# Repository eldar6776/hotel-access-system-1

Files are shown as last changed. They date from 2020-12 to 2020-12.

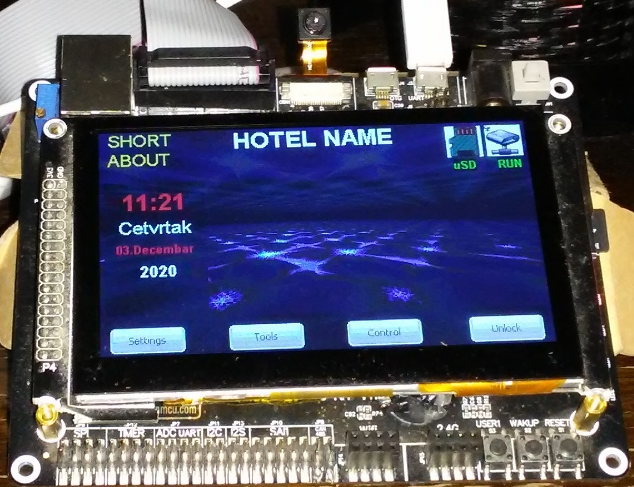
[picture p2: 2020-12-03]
RedDragon429.bmp

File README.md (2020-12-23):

# hotel_access_control_1
The system consists of hotel controllers (RedDragon429 development platform), room controller (STM32F103C8T6 designed pcb), room thermostat (STM32F746ZET designed pcb) and writer/reader for MIFARE cards. RS485 is used to communicate between hotel controller and (0xfffd) room controllers. Each room controller has an individual 16-bit address, a 16-bit group address and a 16-bit broadcast address. All addresses can be adjusted. Each room controller generates and memorates the event log that is transferred every 3 to 10 seconds to the hotel controller, which is still downloaded by the PC application. Communication inside the room is single-wired data + GND. The hotel controller has embedded web server for setting up, update room controllers, temostates, display image change, and more... Tftp server is used transfer new files to a hotel controller uSD card over the network. The complete hardware design is in the "hw" folder.

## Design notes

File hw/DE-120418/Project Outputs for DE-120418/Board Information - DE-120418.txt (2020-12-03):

Board Information Report
Filename     : F:\SkyDrive\OtvoreniProjekti\HotelSaplast\hw\DE-120418\DE-120418.PcbDoc
Date         : 13.4.2018.
Time         : 14:25:55
Time Elapsed : 00:00:00

General
    Board Size, 690milsx830mils
    Components on board, 23
count : 2

Routing Information
    Routing completion, 98,15%
    Connections, 54
    Connections routed, 53
    Connections remaining, 1
count : 4

Layer, Arcs, Pads, Vias, Tracks, Texts, Fills, Regions, ComponentBodies
    Top Layer, 0, 51, 0, 98, 0, 0, 1, 0
    Bottom Layer, 0, 20, 0, 87, 0, 1, 3, 0
    Mechanical 1, 0, 0, 0, 0, 0, 0, 0, 6
    Mechanical 13, 1, 0, 0, 8, 0, 0, 0, 2
    Mechanical 15, 0, 0, 0, 12, 0, 0, 0, 0
    Multi-Layer, 0, 14, 27, 0, 0, 0, 1, 0
    Top Paste, 0, 0, 0, 0, 0, 0, 0, 0
    Top Overlay, 3, 0, 0, 41, 30, 0, 0, 0
    Top Solder, 0, 0, 0, 0, 0, 0, 0, 0
    Bottom Solder, 0, 0, 0, 0, 0, 0, 0, 0
    Bottom Overlay, 0, 0, 0, 9, 20, 0, 0, 0
    Bottom Paste, 0, 0, 0, 0, 0, 0, 0, 0
    Drill Guide, 0, 0, 0, 0, 0, 0, 0, 0
    Keep-Out Layer, 0, 0, 0, 0, 0, 0, 0, 0
    Drill Drawing, 0, 0, 0, 0, 0, 0, 0, 0
count : 15

Drill Pairs, Vias
    Top Layer - Bottom Layer, 27
count : 1

Non-Plated Hole Size, Pads, Vias
count : 0

Plated Hole Size, Pads, Vias
    0mils, 71, 0
    12.992mils, 0, 16
    15.748mils, 0, 11
    35.433mils, 14, 0
count : 4

Non-Plated Slot Size / Length, Pads
count : 0

Plated Slot Size / Length, Pads
count : 0

Non-Plated Square Hole Size, Pads
count : 0

Plated Square Hole Size, Pads
count : 0

Top Layer Annular Ring Size, Count
    12.992mils, 16
    15.748mils, 11
    23.622mils, 14
count : 3

Mid Layer Annular Ring Size, Count
    12.992mils, 16
    15.748mils, 11
    23.622mils, 14
count : 3

Bottom Layer Annular Ring Size, Count
    12.992mils, 16
    15.748mils, 11
    23.622mils, 14
count : 3

Pad Solder Mask, Count
    4mils, 85
count : 1

Pad Paste Mask, Count
    0mils, 85
count : 1

Pad Pwr/Gnd Expansion, Count
    20mils, 85
count : 1

Pad Relief Conductor Width, Count
    10mils, 85
count : 1

Pad Relief Air Gap, Count
    10mils, 85
count : 1

Pad Relief Entries, Count
    4, 85
count : 1

Via Solder Mask, Count
    4mils, 27
count : 1

Via Pwr/Gnd Expansion, Count
    20mils, 27
count : 1

Track Width, Count
    3.937mils, 20
    7.874mils, 46
    10mils, 106
    20mils, 43
    30mils, 40
count : 5

Arc Line Width, Count
    3.937mils, 1
    9.843mils, 3
count : 2

Arc Radius, Count
    4.921mils, 3
    19.685mils, 1
count : 2

Arc Degrees, Count
    360, 4
count : 1

Text Height, Count
    20mils, 48
    60mils, 2
count : 2

Text Width, Count
    3mils, 48
    10mils, 2
count : 2

Net Track Width, Count
    10mils, 19
count : 1

Net Via Size, Count
    31.496mils, 19
count : 1

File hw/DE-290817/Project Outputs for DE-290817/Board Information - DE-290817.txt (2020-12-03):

Board Information Report
Filename     : C:\Users\eldar\Desktop\HotelRoomAccessControlUnit\hw\DE-290817.PcbDoc
Date         : 20.09.2017.
Time         : 18:17:32
Time Elapsed : 00:00:00

General
    Board Size, 2755.906milsx5118.11mils
    Components on board, 176
count : 2

Routing Information
    Routing completion, 100,00%
    Connections, 430
    Connections routed, 430
    Connections remaining, 0
count : 4

Layer, Arcs, Pads, Vias, Tracks, Texts, Fills, Regions, ComponentBodies
    Top Layer, 5, 460, 0, 1414, 0, 10, 12, 0
    Bottom Layer, 7, 26, 0, 742, 0, 5, 26, 0
    Mechanical 1, 0, 0, 0, 24, 2, 0, 0, 21
    Mechanical 13, 7, 0, 0, 100, 0, 1, 0, 20
    Mechanical 15, 0, 0, 0, 150, 0, 0, 0, 0
    Multi-Layer, 0, 68, 271, 0, 0, 0, 1, 0
    Top Paste, 0, 0, 0, 0, 0, 0, 0, 0
    Top Overlay, 41, 0, 0, 413, 358, 0, 0, 0
    Top Solder, 0, 0, 0, 0, 0, 0, 0, 0
    Bottom Solder, 0, 0, 0, 0, 0, 0, 0, 0
    Bottom Overlay, 0, 0, 0, 69, 10, 0, 0, 0
    Bottom Paste, 0, 0, 0, 0, 0, 0, 0, 0
    Drill Guide, 0, 0, 0, 0, 0, 0, 0, 0
    Keep-Out Layer, 3, 0, 0, 4, 0, 0, 0, 0
    Drill Drawing, 0, 0, 0, 0, 0, 0, 0, 0
count : 15

Drill Pairs, Vias
    Top Layer - Bottom Layer, 271
count : 1

Non-Plated Hole Size, Pads, Vias
count : 0

Plated Hole Size, Pads, Vias
    0mils, 486, 0
    15.748mils, 0, 271
    23.622mils, 2, 0
    30mils, 6, 0
    31.496mils, 2, 0
    35.433mils, 46, 0
    47.244mils, 12, 0
count : 7

Non-Plated Slot Size / Length, Pads
count : 0

Plated Slot Size / Length, Pads
count : 0

Non-Plated Square Hole Size, Pads
count : 0

Plated Square Hole Size, Pads
count : 0

Top Layer Annular Ring Size, Count
    11.811mils, 12
    15.748mils, 271
    21.654mils, 2
    23.622mils, 48
    30mils, 6
count : 5

Mid Layer Annular Ring Size, Count
    11.811mils, 12
    15.748mils, 271
    21.654mils, 2
    23.622mils, 48
    30mils, 6
count : 5

Bottom Layer Annular Ring Size, Count
    11.811mils, 12
    15.748mils, 271
    21.654mils, 2
    23.622mils, 48
    30mils, 6
count : 5

Pad Solder Mask, Count
    4mils, 551
    31.496mils, 3
count : 2

Pad Paste Mask, Count
    0mils, 554
count : 1

Pad Pwr/Gnd Expansion, Count
    20mils, 554
count : 1

Pad Relief Conductor Width, Count
    10mils, 554
count : 1

Pad Relief Air Gap, Count
    10mils, 554
count : 1

Pad Relief Entries, Count
    4, 554
count : 1

Via Solder Mask, Count
    4mils, 271
count : 1

Via Pwr/Gnd Expansion, Count
    20mils, 271
count : 1

Track Width, Count
    1.969mils, 24
    3.937mils, 234
    5mils, 301
    7.874mils, 357
    10mils, 1234
    15mils, 3
    19.685mils, 60
    20mils, 317
    30mils, 306
    39.37mils, 7
    50mils, 33
    60mils, 40
count : 12

Arc Line Width, Count
    3.937mils, 7
    5mils, 8
    7.874mils, 3
    9.843mils, 24
    10mils, 14
    23.622mils, 3
    39.37mils, 4
count : 7

Arc Radius, Count
    4.921mils, 24
    11.811mils, 3
    12.5mils, 1
    12.598mils, 8
    19.685mils, 7
    28.248mils, 5
    30.248mils, 3
    41.339mils, 2
    53.151mils, 1
    54.083mils, 1
    60.208mils, 3
    196.85mils, 2
    236.221mils, 1
    314.961mils, 2
count : 14

Arc Degrees, Count
    48, 1
    57, 2
    77, 1
    140, 3
    180, 1
    280, 1
    360, 54
count : 7

Text Height, Count
    15mils, 5
    19.685mils, 346
    20mils, 4
    30mils, 4
    60mils, 10
    118.11mils, 1
count : 6

Text Width, Count
    3.937mils, 351
    4mils, 4
    5mils, 4
    6mils, 2
    10mils, 8
    19.685mils, 1
count : 6

Net Track Width, Count
    5mils, 108
count : 1

Net Via Size, Count
    50mils, 108
count : 1

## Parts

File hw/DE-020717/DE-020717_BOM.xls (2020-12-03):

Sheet: BOM Report
Bill of Materials |  |  | Bill of Materials For PCB Document [DE-020717.PcbDoc]
Source Data From: |  | DE-020717.PcbDoc
Project: |  | DE-020717.PrjPcb
Variant: |  | None
Creation Date: | 2.6.2018. | 16:11:59
Print Date: | 43253 | 43253.67921
Footprint | Comment | LibRef | Designator | Description | Quantity
0603 | 100nF | C0603 | C1, C2, C3, C4, C5, C6, C7, C8, C12, C13, C14, C15, C16, C17, C19, C20, C21, C22, C23, C24, C25, C26, C27, C28, C30, C31, C32, C33, C34, C36, C37, C38, C39, C40, C41, C42, C44, C45, C46, C48, C49, C50, C51, C53, C55, C56, C66, C68, C71, C72, C74, C75, C79 | Ceramic Chip Capacitor - Standard | 59
0805 | C0805 | C0805 | C9, C10, C35 | Ceramic Chip Capacitor - Standard | 3
0603 | C0603 | C0603 | C11, C18, C29, C43, C47, C52 | Ceramic Chip Capacitor - Standard | 6
0805 | 4u7 | C0805 | C54, C57, C70, C73, C81 | Ceramic Chip Capacitor - Standard | 5
0603 | 1uF | C0603 | C67 | Ceramic Chip Capacitor - Standard | 1
3528 | 22uF/16V | 293D156X0004B2 | C83, C84 | Tantamount Commercial, Surface Mount Solid Tantalum Chip Capacitor: 15uF, 20% Tolerance, 4 WVDC @ +85°C, Surge = 5.2V | 2
3528 | 47uF/10V | 293D156X0004B2 | C85, C86 | Tantamount Commercial, Surface Mount Solid Tantalum Chip Capacitor: 15uF, 20% Tolerance, 4 WVDC @ +85°C, Surge = 5.2V | 2
3528 | 100uF | 293D156X0004B2 | C87 | Tantamount Commercial, Surface Mount Solid Tantalum Chip Capacitor: 15uF, 20% Tolerance, 4 WVDC @ +85°C, Surge = 5.2V | 1
0805 | 10uF | C0805 | C90, C93, C94 | Ceramic Chip Capacitor - Standard | 3
1.6X0.8X0.8A | HSMH-C190 | HSMH-C190 | D1 | Surface Mount Chip LED, Red | 1
ONSC-SOD-123-2-425-04_V | STPS1L40M | SMMSD301T1G | D2 | Schottky Barrier Diode, 2-Pin SOD-123, Pb-Free, Tape and Reel | 1
0603 | BLM15AG121 | Inductor_SMD | L1, L2, L3, L5, L7, L8, L9, L10 | Inductor | 8
WE-LQS 252012 | 4,7uH SMD Inductor | SMD inductor | L4 | WE-LQS SMD Power Inductor, L=4.7 µH | 1
HDR1X2 | 3VBAT | NOT FEEDED | P1 | Header, 2-Pin | 1
HDR1X2 | AMBIENT_LIGHT | NOT FEEDED | P2 | Header, 2-Pin | 1
HDR1X2 | AMBIENT_TEMPERATURE | NOT FEEDED | P3 | Header, 2-Pin | 1
10 pin PFC | TOUCH_SCREEN | TS_Connector | P4 | 10 pin PFC connector bottom contacts | 1
HDR2X4 | nRF24L01 | NOT FEEDED | P7 | Header, 4-Pin, Dual row | 1
40 pin FPC | 480x272 RGB TFT LCD AML043056B0-40 | TFT LCD Connector | P8 | 40 pin pfc connector bottom contacts | 1
HDR1X3 | ST-Link Debbuger | NOT FEEDED | P9 | Header, 3-Pin | 1
HDR2X5 | EXPAND | NOT FEEDED | P10 | Header, 5-Pin, Dual row | 1
HDR1X8 | FANCOIL_INTERFACE | NOT FEEDED | P11 | Header, 8-Pin | 1
HDR1X8 | POWER_&_COM | NOT FEEDED | P12 | Header, 8-Pin | 1
SOT23_N | 2N7002 | 2N7002 | Q1, Q2, Q3, Q4 | N-channel Enhancement Mode Vertical D-MOSFET | 4
2-0402 | 10K | ERJ2GE | R1, R2, R3, R4, R5, R6, R7, R8, R9, R10, R11, R14, R15, R16, R17, R18, R19, R20 | Thick Film Chip Resistor, 1 Ohm to 2.2M Ohm Range, 5% Tolerance, 0402 Size, 0.063 W | 18
ERA-0603 | 10K | ERA3Y | R12, R13, R22, R28, R39, R60, R61 | Rectangular Thick Film Chip Resistor, 10 Ohm to 330k Ohm Range, 0.1% and 0.5% Tolerance, 0603 Size, 0.063 W | 7
ERA-0603 | 2K7 | ERA3Y | R21, R23, R25, R26 | Rectangular Thick Film Chip Resistor, 10 Ohm to 330k Ohm Range, 0.1% and 0.5% Tolerance, 0603 Size, 0.063 W | 4
ERA-0603 | 0R | ERA3Y, ERA3Y, ERA3Y, ERA3Y, ERA3Y, ERAV | R24, R27, R34, R36, R37, R48 | Rectangular Thick Film Chip Resistor, 10 Ohm to 330k Ohm Range, 0.1% and 0.5% Tolerance, 0603 Size, 0.063 W, Rectangular Thick Film Chip Resistor, 10 Ohm to 330k Ohm Range, 0.1% and 0.5% Tolerance, 0603 Size, 0.063 W, Rectangular Thick Film Chip Resistor, | 6
ERA-0603 | 560R | ERA3Y | R29, R41 | Rectangular Thick Film Chip Resistor, 10 Ohm to 330k Ohm Range, 0.1% and 0.5% Tolerance, 0603 Size, 0.063 W | 2
ERA-0603 | 1K | ERA3Y | R30, R42, R43 | Rectangular Thick Film Chip Resistor, 10 Ohm to 330k Ohm Range, 0.1% and 0.5% Tolerance, 0603 Size, 0.063 W | 3
ERA-0603 | 330R | ERA3Y | R31 | Rectangular Thick Film Chip Resistor, 10 Ohm to 330k Ohm Range, 0.1% and 0.5% Tolerance, 0603 Size, 0.063 W | 1
ERA-0603 | NF | ERA3Y | R32, R33, R38 | Rectangular Thick Film Chip Resistor, 10 Ohm to 330k Ohm Range, 0.1% and 0.5% Tolerance, 0603 Size, 0.063 W | 3
ERA-0603 | 220R | ERA3Y | R35, R44 | Rectangular Thick Film Chip Resistor, 10 Ohm to 330k Ohm Range, 0.1% and 0.5% Tolerance, 0603 Size, 0.063 W | 2
ERA-0603 | 2K2 | ERA3Y, ERAV, ERAV, ERAV, ERAV, ERAV, ERA3Y | R40, R51, R52, R53, R54, R55, R59 | Rectangular Thick Film Chip Resistor, 10 Ohm to 330k Ohm Range, 0.1% and 0.5% Tolerance, 0603 Size, 0.063 W, Metal Film Thermosensitive Chip Resistor, 0.56 Ohm to 10k Ohm Range, 5% Tolerance, 0603 Size, 0.063 W, Metal Film Thermosensitive Chip Resistor, 0 | 7
ERA-0603 | 100K | ERAV | R45 | Metal Film Thermosensitive Chip Resistor, 0.56 Ohm to 10k Ohm Range, 5% Tolerance, 0603 Size, 0.063 W | 1
ERA-0603 | 4K7 | ERAV, ERA3Y | R46, R58 | Metal Film Thermosensitive Chip Resistor, 0.56 Ohm to 10k Ohm Range, 5% Tolerance, 0603 Size, 0.063 W, Rectangular Thick Film Chip Resistor, 10 Ohm to 330k Ohm Range, 0.1% and 0.5% Tolerance, 0603 Size, 0.063 W | 2
ERA-0805 | 10R | ERAS | R47 | Metal Film Thermosensitive Chip Resistor, 0.56 Ohm to 10k Ohm Range, 5% Tolerance, 0805 Size, 0.1 W | 1
ERA-0603 | 1K2 | ERA3Y | R57 | Rectangular Thick Film Chip Resistor, 10 Ohm to 330k Ohm Range, 0.1% and 0.5% Tolerance, 0603 Size, 0.063 W | 1
LQFP-144_20X20mm | STM32F746ZET | STM32F74XZXT | U1 | STM32F746ZET ARM Cortex M7 microcontroller | 1
MICT-P-86_N | MT48LC4M32B2P-6A | MT48LC4M32B2P-6A | U2 | 128Mb PC133 SDR SDRAM, 4Mb x 32, 6ns, 3.3V, 0 to 70 degC, 86-Pin TSOP, Pb-Free | 1
419A-01_N | MC74VHC1GT14DFT1 | MC74VHC1GT14DFT1 | U3, U5 | Schmitt-Trigger Inverter / Logic Level Shifter with LSTTL-Compatible Inputs | 2
SO16_N | ULN2003A | ULN2003D | U4 | Seven Darlington Array | 1
QFN8_V | STLD40DPUR | STLD40DPUR | U6 | White Led Power Supply For Large Display Backlight, 8-Pin VFDFPN, Tape and Reel | 1
NSO8_N | MAX485CSA | MAX485CSA | U8 | Low-Power, Slew-Rate-Limited RS-485/RS-422 Transceiver | 1
SOP8_N | M24128RMN1 | M24128RMN1 | U9 | 128 K Serial I˛C Bus EEPROM | 1
MICT-SE-8_N | N25Q128A13ESE40E | N25Q128A13ESE40E | U10 | 128 Mb (x1/x2/x4) Serial NOR Flash Memory with Multi I/O, 108 MHz, 2.7 to 3.6 V, 8-pin SO8 Wide (SE), Tray | 1
TO220 | DC/DC BUCK | NOT FEEDED | U11 | Positive Voltage Regulator, 5V, 3-Pin TO-220 | 1
ZZ311 | REG1117-3.3 | REG1117-3.3 | U12 | 800mA and 1A Low Dropout Positive Regulator 2.85V, 3.3V, 5V, and Adjustable | 1
CSM-7 | ECS-110-S-5P | 8MHz | Y1 | Crystal Oscillator | 1
R38 | RTC | 32,768kHz | Y2 | Crystal Oscillator | 1
 |  |  |  |  | 178
Approved |  | Notes

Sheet: Project Information
Project Full Path | F:\SkyDrive\OtvoreniProjekti\HotelSaplast\hw\DE-020717\DE-020717.PrjPcb
Project Filename | DE-020717.PrjPcb
Variant Name | None
Data-Source Filename | DE-020717.PcbDoc
Data-Source Full Path | F:\SkyDrive\OtvoreniProjekti\HotelSaplast\hw\DE-020717\DE-020717.PcbDoc
Title | Bill of Materials For PCB Document [DE-020717.PcbDoc]
Total Quantity | 178
Report Time | 16:11:59
Report Date | 2.6.2018.
Report Date & Tine | 2.6.2018. 16:11:59
Output Name | Bill of Materials
Output Type | BOM_PartType
Output Generator Name | BOM
Output Generator Description | Bill of Materials

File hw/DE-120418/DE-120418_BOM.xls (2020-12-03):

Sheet: BOM Report
Bill of Materials |  |  | AUDIO CODEC
Source Data From: |  | DE-120418.PrjPcb
Project: |  | DE-120418.PrjPcb
Variant: |  | None
Creation Date: | 13.4.2018. | 14:25:38
Print Date: | 43203 | 43203.60118
Footprint | Comment | LibRef | Designator | Description | Quantity
3528 | 47uF/10V | 293D156X0004B2 | C1 | Tantamount Commercial, Surface Mount Solid Tantalum Chip Capacitor: 15uF, 20% Tolerance, 4 WVDC @ +85°C, Surge = 5.2V | 1
0805 | 10uF | C0805 | C2, C9 | Ceramic Chip Capacitor - Standard | 2
0603 | 100nF | C0603 | C3, C11, C12 | Ceramic Chip Capacitor - Standard | 3
0805 | 4u7 | C0805 | C4, C6, C7, C13, C14 | Ceramic Chip Capacitor - Standard | 5
3528 | 100uF | 293D156X0004B2 | C8 | Tantamount Commercial, Surface Mount Solid Tantalum Chip Capacitor: 15uF, 20% Tolerance, 4 WVDC @ +85°C, Surge = 5.2V | 1
0603 | 220pF | C0603 | C15 | Ceramic Chip Capacitor - Standard | 1
0603 | 1uF | C0603 | C16, C17 | Ceramic Chip Capacitor - Standard | 2
INDC1608L | BLM15AG121 | Inductor_SMD | L1 | Inductor | 1
HDR1X2 | SPEAKER | Header 2 | P1 | Header, 2-Pin | 1
HDR1X2 | MIC | Header 2 | P2 | Header, 2-Pin | 1
HDR2X5 | AUDIO_CODEC | Header 5X2 | P3 | Header, 5-Pin, Dual row | 1
ERA-0603 | 47K | ERAV | R1 | Metal Film Thermosensitive Chip Resistor, 0.56 Ohm to 10k Ohm Range, 5% Tolerance, 0603 Size, 0.063 W | 1
ERA-0603 | 680R | ERAV | R2 | Metal Film Thermosensitive Chip Resistor, 0.56 Ohm to 10k Ohm Range, 5% Tolerance, 0603 Size, 0.063 W | 1
ERA-0603 | 0R | ERAV | R3 | Metal Film Thermosensitive Chip Resistor, 0.56 Ohm to 10k Ohm Range, 5% Tolerance, 0603 Size, 0.063 W | 1
QFN32_N | WM8976 | WM8976 | U1 | Stereo CODEC with speaker driver | 1
 |  |  |  |  | 23
Approved |  | Notes

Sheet: Project Information
Project Full Path | F:\SkyDrive\OtvoreniProjekti\HotelSaplast\hw\DE-120418\DE-120418.PrjPcb
Project Filename | DE-120418.PrjPcb
Variant Name | None
Data-Source Filename | DE-120418.PrjPcb
Data-Source Full Path | F:\SkyDrive\OtvoreniProjekti\HotelSaplast\hw\DE-120418\DE-120418.PrjPcb
Title | AUDIO CODEC
Total Quantity | 23
Report Time | 14:25:38
Report Date | 13.4.2018.
Report Date & Tine | 13.4.2018. 14:25:38
Output Name | Bill of Materials
Output Type | BOM_PartType
Output Generator Name | BOM
Output Generator Description | Bill of Materials

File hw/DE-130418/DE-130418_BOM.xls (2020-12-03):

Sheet: BOM Report
Bill of Materials |  |  | Bill of Materials For PCB Document [DE-130418.PcbDoc]
Source Data From: |  | DE-130418.PcbDoc
Project: |  | DE-130418.PrjPcb
Variant: |  | None
Creation Date: | 13.4.2018. | 16:10:28
Print Date: | 43203 | 43203.67416
Footprint | Comment | LibRef | Designator | Description | Quantity
0603 | 100nF | C0603 | C1 | Ceramic Chip Capacitor - Standard | 1
0805 | 4u7 | C0805 | C2 | Ceramic Chip Capacitor - Standard | 1
ONSC-TO-220-3-221A-07 | BTA16-600 | BTA08-600BW3G | D1, D2, D3 | Triacs, Silicon Bidirectional Thyristor, 3-Pin TO-220, Pb-Free, Tube | 3
15-43-8501 | 15-43-8501 | 15-43-8501 | J1 | Right Angle, Standard Profile, RJ-45 Keyed, Unshielded PCB Jack | 1
TERMINAL BLOK 2 | 220VAC | TERMINAL BLOK 2 | P1 | Terminal blok konektor 5 mm | 1
TERMINAL BLOK 2 |  | TERMINAL BLOK 2 | P2, P3 | Terminal blok konektor 5 mm | 2
HDR1X3 | AUX | Header 3 | P4 | Header, 3-Pin | 1
ERA-0805 | 330R | ERAS | R1, R4, R7 | Metal Film Thermosensitive Chip Resistor, 0.56 Ohm to 10k Ohm Range, 5% Tolerance, 0805 Size, 0.1 W | 3
RD6.35x2.3 | 360R | ERDS1T | R2, R3, R5, R6, R8, R9 | Carbon Film Resistor, 1 Ohm to 3.3M Ohm Range, 5% Tolerance, 0.5 W | 6
DIP6 | MOC3081 | MOC3081 | U1, U2, U3 | Zero-Cross Optoisolator Triac Driver | 3
 |  |  |  |  | 22
Approved |  | Notes

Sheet: Project Information
Project Full Path | F:\SkyDrive\OtvoreniProjekti\HotelSaplast\hw\DE-130418\DE-130418.PrjPcb
Project Filename | DE-130418.PrjPcb
Variant Name | None
Data-Source Filename | DE-130418.PcbDoc
Data-Source Full Path | F:\SkyDrive\OtvoreniProjekti\HotelSaplast\hw\DE-130418\DE-130418.PcbDoc
Title | Bill of Materials For PCB Document [DE-130418.PcbDoc]
Total Quantity | 22
Report Time | 16:10:28
Report Date | 13.4.2018.
Report Date & Tine | 13.4.2018. 16:10:28
Output Name | Bill of Materials
Output Type | BOM_PartType
Output Generator Name | BOM
Output Generator Description | Bill of Materials

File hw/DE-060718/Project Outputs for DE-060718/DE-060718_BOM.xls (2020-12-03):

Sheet: BOM Report
Bill of Materials |  |  | Bill of Materials For PCB Document [DE-060718.PcbDoc]
Source Data From: |  | DE-060718.PcbDoc
Project: |  | DE-060718.PrjPcb
Variant: |  | None
Creation Date: | 9.7.2018. | 21:12:18
Print Date: | 43290 | 43290.88359
Footprint | Comment | LibRef | Designator | Description | Quantity
0603 | 100nF | C0603 | C1, C14, C18, C19, C22, C26, C28, C29 | Ceramic Chip Capacitor - Standard | 8
0603 | 1nF | C0603 | C2 | Ceramic Chip Capacitor - Standard | 1
0603 | 1uF | C0603 | C3, C30 | Ceramic Chip Capacitor - Standard | 2
0603 | 22pF | C0603 | C4, C11 | Ceramic Chip Capacitor - Standard | 2
0603 | 220pF | C0603 | C5, C8 | Ceramic Chip Capacitor - Standard | 2
0603 | NF | C0603 | C6, C9 | Ceramic Chip Capacitor - Standard | 2
0603 | 100pF | C0603 | C7, C10 | Ceramic Chip Capacitor - Standard | 2
0603 | 15pF | C0603 | C12, C13 | Ceramic Chip Capacitor - Standard | 2
0805 | 10uF | C0805 | C15, C16, C17, C20, C21, C23, C24, C25, C27 | Ceramic Chip Capacitor - Standard | 9
0603 | 10nF | C0603 | C31 | Ceramic Chip Capacitor - Standard | 1
SOD323 | 1N4148 | 1PS76SB10 | D1 | Schottky Barrier Diode | 1
LED 3mm | LED_1 | LED 3mm | D2 |  | 1
LED 3mm | LED_2 | LED 3mm | D3 |  | 1
ONSC-SOD-123-2-425-04_V | ZD6V8 | SZMMSZ6V8T1G | D4 | Zener Voltage Regulator, 500 mW, 2-Pin SOD-123, Pb-Free, Tape and Reel | 1
SMD-0805 | 560nH | 74279207 | L1, L2 | SMD EMI Suppression Ferrite Bead WE-CBF, Z = 100 Ohm | 2
SMD-0805 | 74279207 | 74279207 | L3 | SMD EMI Suppression Ferrite Bead WE-CBF, Z = 100 Ohm | 1
HDR1X4 | uC | Header 4 | P1 | Header, 4-Pin | 1
HDR1X4 | MFRC | Header 4 | P2 | Header, 4-Pin | 1
ICSP | ICSP | ICSP | P3 | ICSP connection pads | 1
HDR1X5 | CON1 | Header 5 | P4 | Header, 5-Pin | 1
SOT23_N | MMBT2222 | BC817 | Q1, Q2 | NPN General-purpose Transistor | 2
ERA-0603 | 1K8 | ERJ3RS | R1, R3 | Low Ohmic Value Thick Film Chip Resistor, 0.1 Ohm to 0.2 Ohm Range, 1%, 2% and 5% Tolerance, 0603 Size, 0.1 W | 2
ERA-0603 | 10K | ERJ3RS | R2 | Low Ohmic Value Thick Film Chip Resistor, 0.1 Ohm to 0.2 Ohm Range, 1%, 2% and 5% Tolerance, 0603 Size, 0.1 W | 1
ERA-0603 | 1R8 | ERJ3RS | R4, R5 | Low Ohmic Value Thick Film Chip Resistor, 0.1 Ohm to 0.2 Ohm Range, 1%, 2% and 5% Tolerance, 0603 Size, 0.1 W | 2
ERA-0603 | 120R | ERJ3RS | R6, R7, R8 | Low Ohmic Value Thick Film Chip Resistor, 0.1 Ohm to 0.2 Ohm Range, 1%, 2% and 5% Tolerance, 0603 Size, 0.1 W | 3
ERA-0603 | 1K | ERJ3RS | R9 | Low Ohmic Value Thick Film Chip Resistor, 0.1 Ohm to 0.2 Ohm Range, 1%, 2% and 5% Tolerance, 0603 Size, 0.1 W | 1
QFN32 | MFRC522 | MFRC522 | U1 | MIFARE reader writer | 1
SOP4 | PC817 | PC817 optocoupler | U2 | 4-Pin Phototransistor Optocoupler | 1
STM-TSSOP20_N | STM32F030F4P6 | STM32F030F4P6 | U3 | ARM Cortex-M0 32-bit MCU, 16 KB Flash, 4 KB Internal RAM, 15 I/Os, 20-pin TSSOP, -40 to 85 degC, Tube | 1
SOT-223_N | AMS1117-3.3 | LD1117AS33TR | U4 | 1A, Low Drop Positive Voltage Regulator, 3.3V, 4-Pin SOT-223, Tape and Reel | 1
HC49/4H_SMX | 27,12 MHz | HC49/4H_SMX | Y1 | Surface Mount Quartz Crystal | 1
 |  |  |  |  | 58
Approved |  | Notes

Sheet: Project Information
Project Full Path | F:\SkyDrive\OtvoreniProjekti\HotelSaplast\hw\DE-060718\DE-060718.PrjPcb
Project Filename | DE-060718.PrjPcb
Variant Name | None
Data-Source Filename | DE-060718.PcbDoc
Data-Source Full Path | F:\SkyDrive\OtvoreniProjekti\HotelSaplast\hw\DE-060718\DE-060718.PcbDoc
Title | Bill of Materials For PCB Document [DE-060718.PcbDoc]
Total Quantity | 58
Report Time | 21:12:18
Report Date | 9.7.2018.
Report Date & Tine | 9.7.2018. 21:12:18
Output Name | Bill of Materials
Output Type | BOM_PartType
Output Generator Name | BOM
Output Generator Description | Bill of Materials

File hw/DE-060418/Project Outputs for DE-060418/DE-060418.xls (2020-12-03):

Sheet: BOM Report
Bill of Materials |  |  | LUK FANCOIL INTERFACE
Source Data From: |  | DE-060418.PrjPcb
Project: |  | DE-060418.PrjPcb
Variant: |  | None
Creation Date: | 8.4.2018. | 17:41:46
Print Date: | 43198 | 43198.73737
Footprint | Comment | LibRef | Designator | Description | Quantity
0805 | 4u7 | C0805 | C1, C4 | Ceramic Chip Capacitor - Standard | 2
VP52-2.5 | 47nF/X2 | VP52BA103 | C2, C5, C6 | Dipped Radial Multilayer Ceramic Capacitor COG (NPO): 10nF | 3
0603 | 100nF | C0603 | C3, C7 | Ceramic Chip Capacitor - Standard | 2
SOD323 | 1N4148 | BAS321 | D1, D2, D3, D4, D5 | General-purpose Diode | 5
ONSC-TO-220-3-221A-07 | BTA16-600 | BTA08-600BW3G | D6, D7 | Triacs, Silicon Bidirectional Thyristor, 3-Pin TO-220, Pb-Free, Tube | 2
15-43-8501 | THERMOSTAT | 15-43-8501 | J1 | Right Angle, Standard Profile, RJ-45 Keyed, Unshielded PCB Jack | 1
HDR1X3 | MOTOR_RPM_SENSOR | Header 3 | P1 | Header, 3-Pin | 1
TERMINAL BLOK 2 | 220VAC | TERMINAL BLOK 2 | P2 | Terminal blok konektor 3,5 mm | 1
TERMINAL BLOK 3 | FAN_MOTOR | TERMINAL BLOK 3 | P3 | 3 pinski terminal blok konektor | 1
TERMINAL BLOK 2 | COOLING_VALVE | TERMINAL BLOK 2 | P4 | Terminal blok konektor 3,5 mm | 1
HDR1X2 | NTC_2K_FANCOIL | Header 2 | P5 | Header, 2-Pin | 1
HDR1X2 | STATUS_LED | Header 2 | P6 | Header, 2-Pin | 1
SOT23_N | BC817 | BC817 | Q1 | NPN General-purpose Transistor | 1
6-0805 | 1K | ERJ6BQ | R1, R2, R3, R15, R21 | Low Ohmic Value Thick Film Chip Resistor, 0.22 Ohm to 9.1 Ohm Range, 1%, 2% and 5% Tolerance, 0805 Size, 0.25 W | 5
6-0805 | 56K | ERJ6BQ | R4, R5, R6, R7, R11, R12, R13, R14 | Low Ohmic Value Thick Film Chip Resistor, 0.22 Ohm to 9.1 Ohm Range, 1%, 2% and 5% Tolerance, 0805 Size, 0.25 W | 8
6-0805 | 10K | ERJ6BQ | R8 | Low Ohmic Value Thick Film Chip Resistor, 0.22 Ohm to 9.1 Ohm Range, 1%, 2% and 5% Tolerance, 0805 Size, 0.25 W | 1
6-0805 | 220R | ERJ6BQ | R9, R10, R16, R17, R18, R19, R22, R23, R24, R25 | Low Ohmic Value Thick Film Chip Resistor, 0.22 Ohm to 9.1 Ohm Range, 1%, 2% and 5% Tolerance, 0805 Size, 0.25 W | 10
6-0805 | 330R | ERJ6BQ | R20, R26, R27 | Low Ohmic Value Thick Film Chip Resistor, 0.22 Ohm to 9.1 Ohm Range, 1%, 2% and 5% Tolerance, 0805 Size, 0.25 W | 3
M14A_N | 74AC14SC | 74AC14SC | U1 | Hex Schmitt-Trigger Inverter, 14-Pin SOIC, Commercial Grade | 1
DIP-4 | PC817 | Optoisolator1 | U2 | 4-Pin Phototransistor Optocoupler | 1
DIP6 | MOC3052 | MOC3081 | U3 | Zero-Cross Optoisolator Triac Driver | 1
DIP6 | MOC3083 | MOC3081 | U4 | Zero-Cross Optoisolator Triac Driver | 1
 |  |  |  |  | 53
Approved |  | Notes

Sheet: Project Information
Project Full Path | F:\SkyDrive\OtvoreniProjekti\HotelSaplast\hw\DE-060418\DE-060418.PrjPcb
Project Filename | DE-060418.PrjPcb
Variant Name | None
Data-Source Filename | DE-060418.PrjPcb
Data-Source Full Path | F:\SkyDrive\OtvoreniProjekti\HotelSaplast\hw\DE-060418\DE-060418.PrjPcb
Title | LUK FANCOIL INTERFACE
Total Quantity | 53
Report Time | 17:41:46
Report Date | 8.4.2018.
Report Date & Tine | 8.4.2018. 17:41:46
Output Name | Bill of Materials
Output Type | BOM_PartType
Output Generator Name | BOM
Output Generator Description | Bill of Materials

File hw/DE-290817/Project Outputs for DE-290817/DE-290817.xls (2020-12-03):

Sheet: BOM Report
Bill of Materials |  |  | Bill of Materials For Project [DE-290817.PrjPcb] (No PCB Document Selected)
Source Data From: |  | DE-290817.PrjPcb
Project: |  | DE-290817.PrjPcb
Variant: |  | None
Creation Date: | 05.09.2017. | 18:24:49
Print Date: | 42983 | 42983.77797
Footprint | Comment | LibRef | Designator | Description | Quantity
0603 | 100nF | C0603 | C100, C102, C104, C105, C110, C112, C113, C114, C115, C116, C117, C118, C121, C122, C201, C202, C203, C204, C205, C214, C215, C216, C217, C227, C231, C235, C236, C300, C302, C303 | Ceramic Chip Capacitor - Standard | 30
0805 | 10uF | C0805 | C101, C103, C109, C119, C232, C233, C234, C237, C238, C301 | Ceramic Chip Capacitor - Standard | 10
0603 | 22pF | C0603 | C106, C107, C305, C312 | Ceramic Chip Capacitor - Standard | 4
0603 | 6p8 | C0603 | C108, C111 | Ceramic Chip Capacitor - Standard | 2
0603 | 1uF | C0603 | C120 | Ceramic Chip Capacitor - Standard | 1
0603 | 22nF | C0603 | C228 | Ceramic Chip Capacitor - Standard | 1
EEEHA1H101P | 220uF/50V | EEEHA1H101P | C229 | Aluminum Electrolytic Capacitors (SMD Type) | 1
EEEHA1H101P | 220uF/16V | EEEHA1C221P | C230 | Aluminum Electrolytic Capacitors (SMD Type) | 1
0603 | 1nF | C0603 | C304 | Ceramic Chip Capacitor - Standard | 1
0603 | 220pF | C0603 | C306, C309 | Ceramic Chip Capacitor - Standard | 2
0603 | NF | C0603 | C307, C310 | Ceramic Chip Capacitor - Standard | 2
0603 | 100pF | C0603 | C308, C311 | Ceramic Chip Capacitor - Standard | 2
0603 | 15pF | C0603 | C313, C314 | Ceramic Chip Capacitor - Standard | 2
1.6X0.8X0.8 | LED_BLUE | HSMZ-C190 | D100 | High Performance Chip LED, Red | 1
1.6X0.8X0.8 | LED_RED | HSMZ-C190 | D101 | High Performance Chip LED, Red | 1
SOD323 | 1N4148 | 1N4148 | D102, D105, D106, D204 | Schottky Barrier Diode, Schottky Barrier Diode, Schottky Barrier Diode, General-purpose Diode | 4
1.6X0.8X0.8 | LED_GREEN | HSMZ-C190 | D103 | High Performance Chip LED, Red | 1
1.6X0.8X0.8 | LED_WHITE | HSMZ-C190 | D104 | High Performance Chip LED, Red | 1
PIN2 | NF | Photo Sen | D107 | Photosensitive RESISTOR NTC 10K | 1
SOD323 | 3V3 | MM3Z3V3 | D200, D201, D202, D203, D205, D206, D207, D208 | Zener diode | 8
ONSC-SMA-2-403D-02_C_V | SR3100 | MBRA320T3G | D209 | Schottky Power Rectifier, 2-Pin SMA, Pb-Free, Tape and Reel | 1
SMD-0805 | 120R | 74279202 | L100 | SMD EMI Suppression Ferrite Bead WE-CBF, Z = 120 Ohm | 1
WE-PD-XL | wurth WE-PD=744770133 | 744770133 | L200 | SMD-Shielded Power Inductor WE-PD, L = 33 µH | 1
SMD-0805 | 74279207 | 74279207 | L300 | SMD EMI Suppression Ferrite Bead WE-CBF, Z = 100 Ohm | 1
SMD-0805 | 560nH/300mA | 74279207 | L301, L302 | SMD EMI Suppression Ferrite Bead WE-CBF, Z = 100 Ohm | 2
BUZZER | Buzzer 5Vdc | BUZZER | LS1 | 5Vdc PCB buzzer | 1
HDR2X4 | NRF24L01 | Header 4X2 | P100 | Header, 4-Pin, Dual row | 1
DISPLAY CON | SPI TFT DISPLAY | DISPLAY CONNECTOR | P101 | DISPLAY ILI9341 240x320 CONNECTOR | 1
ICSP | ICSP | ICSP | P102 | ICSP connection pads | 1
HDR1X2 | RTC BATTERY | Header 2 | P103 | Header, 2-Pin | 1
HDR2X17 | CON 1 | Header 17X2 | P201 | Header, 17-Pin, Dual row | 1
FB241_6 | FB241 | TERMINAL BLOCK 6 | P202 | PCB MOUNT TERMINAL BLOCK 2.5MM PITCH | 1
SOT23_N | MMBT2222 | MMBT2222 | Q100 | NPN General-purpose Transistor | 1
SOT23_N | 2N7002 | 2N7002 | Q200, Q206, Q207, Q209, Q210 | N-channel Enhancement Mode Field-effect Transistor | 5
ONSC-SOIC-8-751-07_V | STS4DNF60L | STS4DNF60L | Q201 | Power MOSFET, 40 V, 5.8 A, Dual N-Channel, 8-Pin SOIC, Pb-Free, Tape and Reel | 1
SOT23_N | AO3400 | AO3400 | Q202, Q203, Q204, Q205, Q208, Q211 | N-channel Enhancement Mode Field-effect Transistor | 6
ERA-0603 | 120R | ERAV | R100, R103, R105 | Metal Film Thermosensitive Chip Resistor, 0.56 Ohm to 10k Ohm Range, 5% Tolerance, 0603 Size, 0.063 W | 3
ERA-0603 | 100R | ERAV | R101 | Metal Film Thermosensitive Chip Resistor, 0.56 Ohm to 10k Ohm Range, 5% Tolerance, 0603 Size, 0.063 W | 1
ERA-0603 | 220R | ERAV | R102 | Metal Film Thermosensitive Chip Resistor, 0.56 Ohm to 10k Ohm Range, 5% Tolerance, 0603 Size, 0.063 W | 1
ERA-0603 | 100K | ERAV | R104 | Metal Film Thermosensitive Chip Resistor, 0.56 Ohm to 10k Ohm Range, 5% Tolerance, 0603 Size, 0.063 W | 1
ERA-0603 | 4R7 | ERAV | R106 | Metal Film Thermosensitive Chip Resistor, 0.56 Ohm to 10k Ohm Range, 5% Tolerance, 0603 Size, 0.063 W | 1
ERA-0603 | 1K | ERAV | R107, R108, R109 | Metal Film Thermosensitive Chip Resistor, 0.56 Ohm to 10k Ohm Range, 5% Tolerance, 0603 Size, 0.063 W | 3
ERA-0603 | 4K7 | ERAV | R110, R111 | Metal Film Thermosensitive Chip Resistor, 0.56 Ohm to 10k Ohm Range, 5% Tolerance, 0603 Size, 0.063 W | 2
ERA-0603 | 10K | ERAV | R112, R113, R115, R117, R203, R205, R207, R211, R212, R213, R215, R216, R217, R218, R219, R221, R222, R223, R224, R225, R226, R228, R234, R235, R236, R238, R244, R245, R247, R304 | Metal Film Thermosensitive Chip Resistor, 0.56 Ohm to 10k Ohm Range, 5% Tolerance, 0603 Size, 0.063 W | 30
ERA-0603 | NF | ERAV | R114 | Metal Film Thermosensitive Chip Resistor, 0.56 Ohm to 10k Ohm Range, 5% Tolerance, 0603 Size, 0.063 W | 1
ERA-0603 | 100K | ERAV | R118 | Metal Film Thermosensitive Chip Resistor, 0.56 Ohm to 10k Ohm Range, 5% Tolerance, 0603 Size, 0.063 W | 1
ERA-0603 | 0R | ERAV | R201, R209 | Metal Film Thermosensitive Chip Resistor, 0.56 Ohm to 10k Ohm Range, 5% Tolerance, 0603 Size, 0.063 W | 2
RD3.2x1.7 | NF | ERD6FC | R204 | Flame-Retardant Fuse Type Carbon Film Resistor, 4.7 Ohm to 1k Ohm Range, 2% and 5% Tolerance, 0.166 W | 1
ERA-0603 | 10R | ERAV | R227 | Metal Film Thermosensitive Chip Resistor, 0.56 Ohm to 10k Ohm Range, 5% Tolerance, 0603 Size, 0.063 W | 1
ERA-0603 | 2K2 | ERAV | R237, R239, R240, R242, R243 | Metal Film Thermosensitive Chip Resistor, 0.56 Ohm to 10k Ohm Range, 5% Tolerance, 0603 Size, 0.063 W | 5
ERA-0603 | 1K2 | ERAV | R241 | Metal Film Thermosensitive Chip Resistor, 0.56 Ohm to 10k Ohm Range, 5% Tolerance, 0603 Size, 0.063 W | 1
ERA-0603 | 3K3 | ERAV | R246 | Metal Film Thermosensitive Chip Resistor, 0.56 Ohm to 10k Ohm Range, 5% Tolerance, 0603 Size, 0.063 W | 1
3-0603 | 1K8 | ERJ3RS | R300, R301 | Low Ohmic Value Thick Film Chip Resistor, 0.1 Ohm to 0.2 Ohm Range, 1%, 2% and 5% Tolerance, 0603 Size, 0.1 W | 2
3-0603 | 1R8 | ERJ3RS | R302, R303 | Low Ohmic Value Thick Film Chip Resistor, 0.1 Ohm to 0.2 Ohm Range, 1%, 2% and 5% Tolerance, 0603 Size, 0.1 W | 2
TACTILE_SWITCH | TAMPER | TACKTILE_SWITCH | S100 | Through hole tacktile switch 5mm button high max. | 1
SOP8 | CAP1293 | CAP1293 | U100 | 3-Channel Capacitive Touch Sensor with Proximity Detection & Signal Guard | 1
D016_N | SN74HC595D | SN74HC595D | U101 | 8-Bit Shift Register with 3-State Output Registers | 1
STM-LQFP48_N | STM32F103C8T6 | STM32F103C8T6 | U102 | ARM Cortex-M3 32-bit MCU, 64 KB Flash, 20 KB Internal RAM, 37 I/Os, 48-pin LQFP, -40 to 85 degC, Tray | 1
SOIC-SN8_N | FT24C128A | AT24C128 | U103 | 64Kbit, 400kHz, 1.7V, I2C Serial EEPROM, 8-Pin SOIC 150mil, Commercial Temperature | 1
SOIJ-SM8_N | W25Q64 | W25Q64 | U104 | 64K SPI Bus Serial EEPROM, 8-Pin SOIC, Industrial Temperature | 1
NSO8_M | MAX485ESA | MAX485ESA | U202 | Low-Power, Slew-Rate-Limited RS-485/RS-422 Transceiver | 1
TS5B_N | LM2596S-ADJ | LM2596S-ADJ | U203 | SIMPLE SWITCHER® Power Converter 150 KHz 3A Step-Down Voltage Regulator, 5-pin TO-263 | 1
ZZ311 | REG1117-3.3 | REG1117-3.3 | U204 | 800mA and 1A Low Dropout Positive Regulator 2.85V, 3.3V, 5V, and Adjustable | 1
QFN32 | MFRC522 | MFRC522 | U300 | MIFARE reader writer | 1
HC49/4H_SMX | 8MHz | HC49/4H_SMX | Y100 | Surface Mount Quartz Crystal | 1
R26 | 32.768MHz | R26-32.768 | Y101 | Tuning Fork Crystal Unit | 1
HC49/4H_SMX | 27,12 MHz | ECS-80-20-1 | Y300 | Surface Mount Quartz Crystal | 1
 |  |  |  |  | 174
Approved |  | Notes

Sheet: Project Information
Project Full Path | C:\Users\eldar\Desktop\HotelRoomAccessControlUnit\hw\DE-290817.PrjPcb
Project Filename | DE-290817.PrjPcb
Variant Name | None
Data-Source Filename | DE-290817.PrjPcb
Data-Source Full Path | C:\Users\eldar\Desktop\HotelRoomAccessControlUnit\hw\DE-290817.PrjPcb
Title | Bill of Materials For Project [DE-290817.PrjPcb] (No PCB Document Selected)
Total Quantity | 174
Report Time | 18:24:49
Report Date | 05.09.2017.
Report Date & Tine | 05.09.2017. 18:24:49
Output Name | Bill of Materials
Output Type | BOM_PartType
Output Generator Name | BOM
Output Generator Description | Bill of Materials

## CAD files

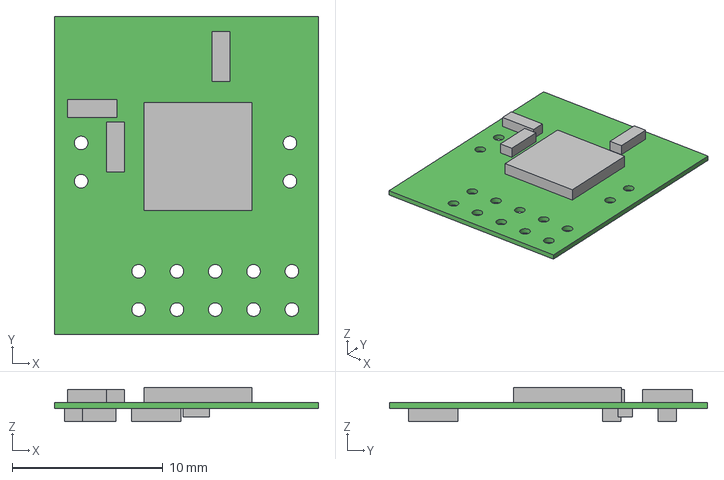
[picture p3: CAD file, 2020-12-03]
hw/DE-120418/DE-120418.step
17.5 x 21.1 x 2.28 mm

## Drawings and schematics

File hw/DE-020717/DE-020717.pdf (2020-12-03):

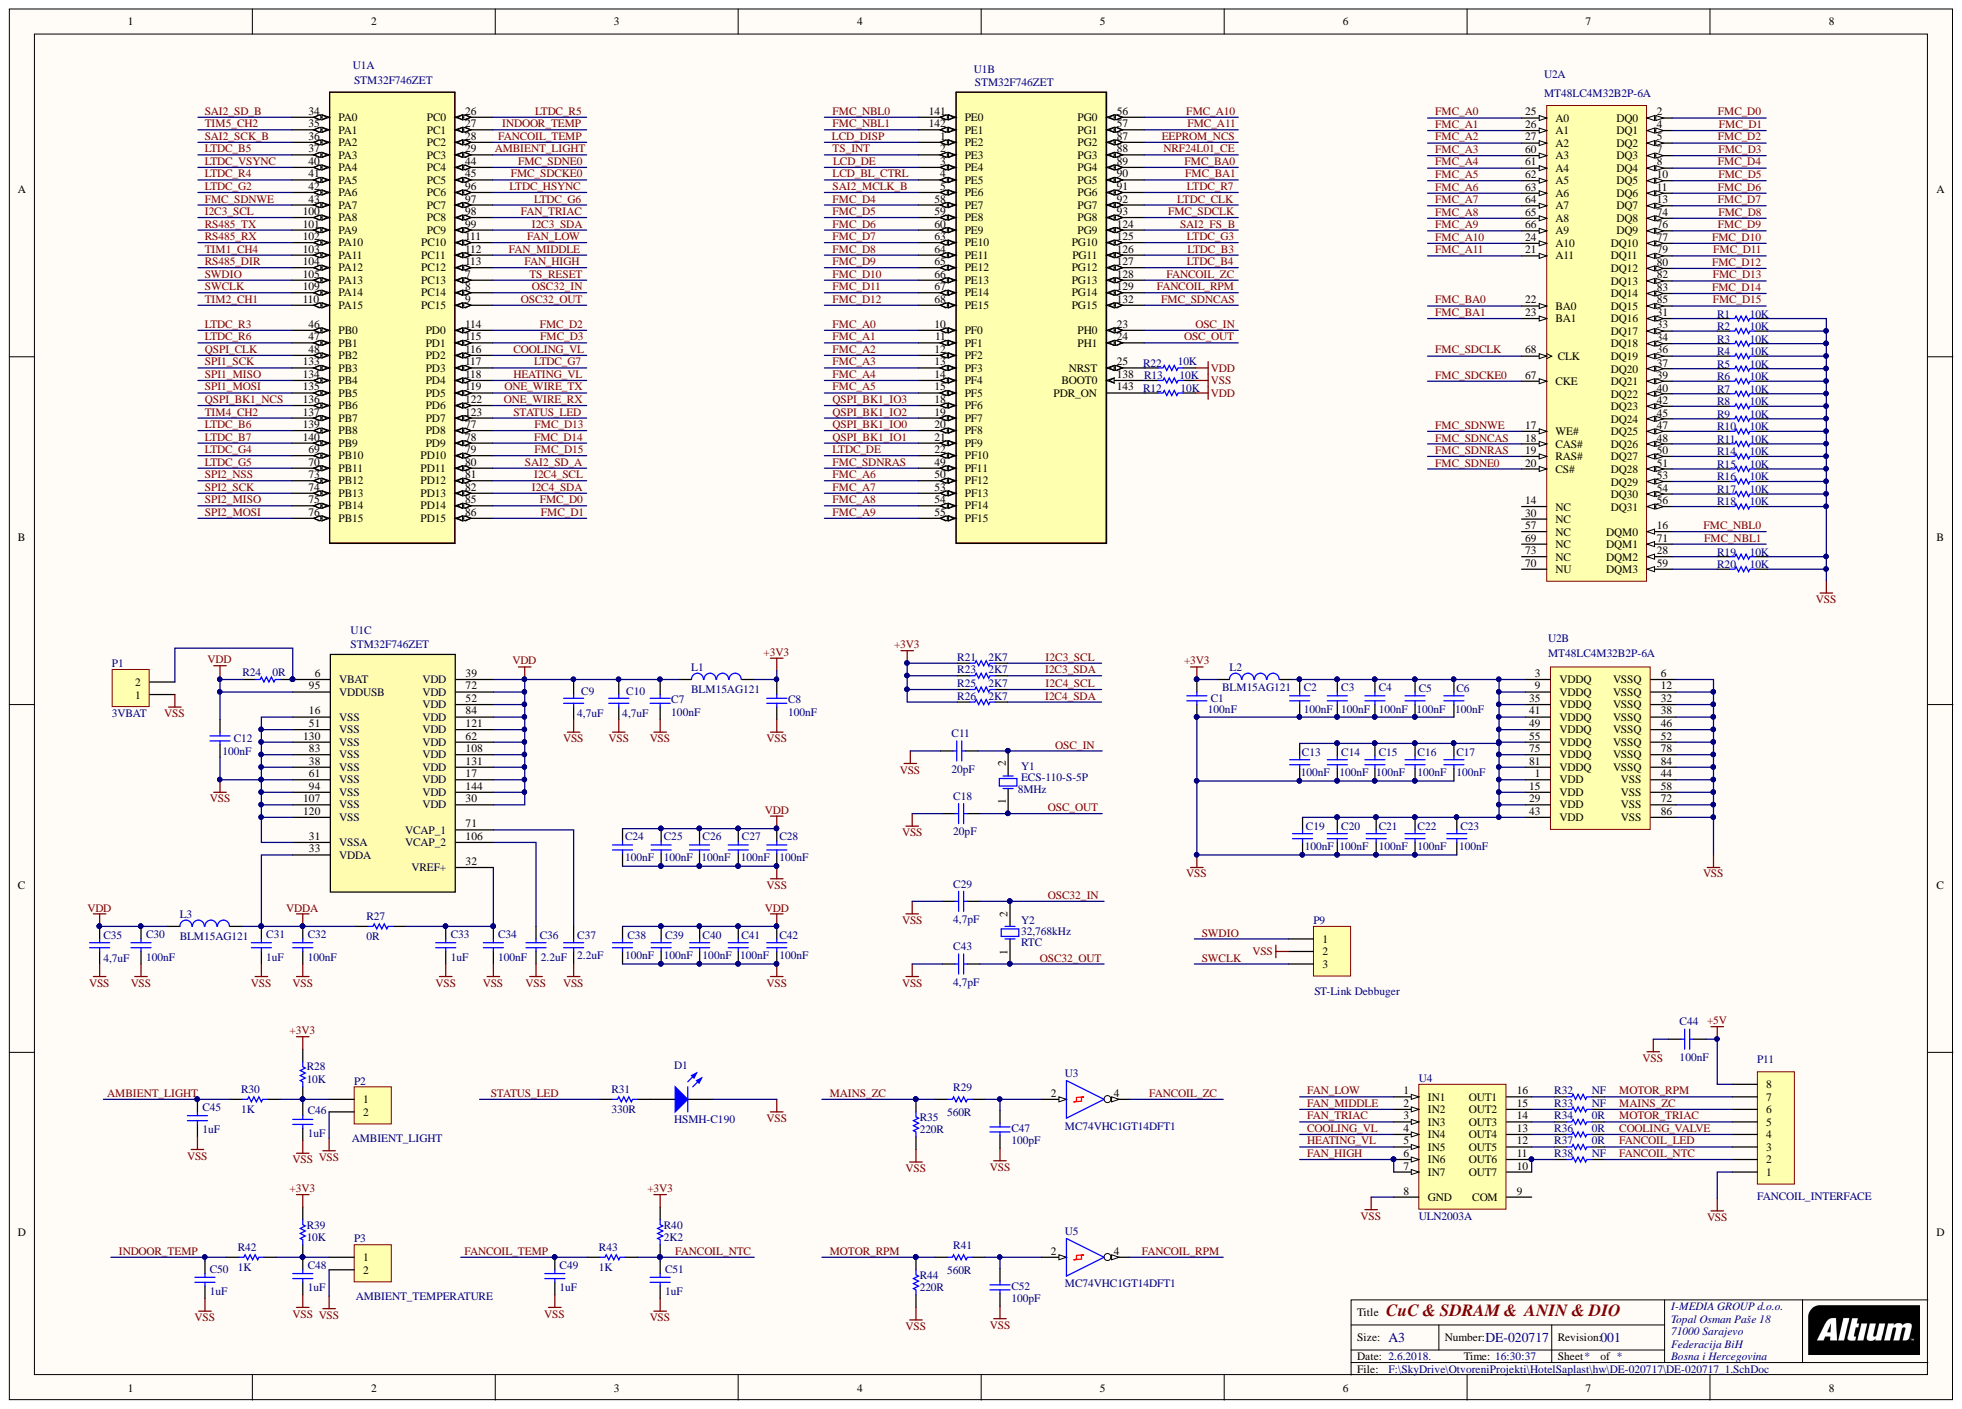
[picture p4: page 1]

NC 69 | FMC_NBL1
NC 73 | R19 10K
NU 70 | R20 10K

CuC & SDRAM & ANIN & DIO Title | I-MEDIA GROUP d.o.o. Topal Osman Paše 18 71000 Sarajevo Federacija BiH Bosna i Hercegovina

Size: A3 | Number: DE-020717 | Revision: 001
Date: 2.6.2018. Time: 16:30:37 | | Sheet * of *

F:\SkyDrive\OtvoreniProjekti\HotelSaplast\hw\DE-020717\DE-020717_1.SchDoc

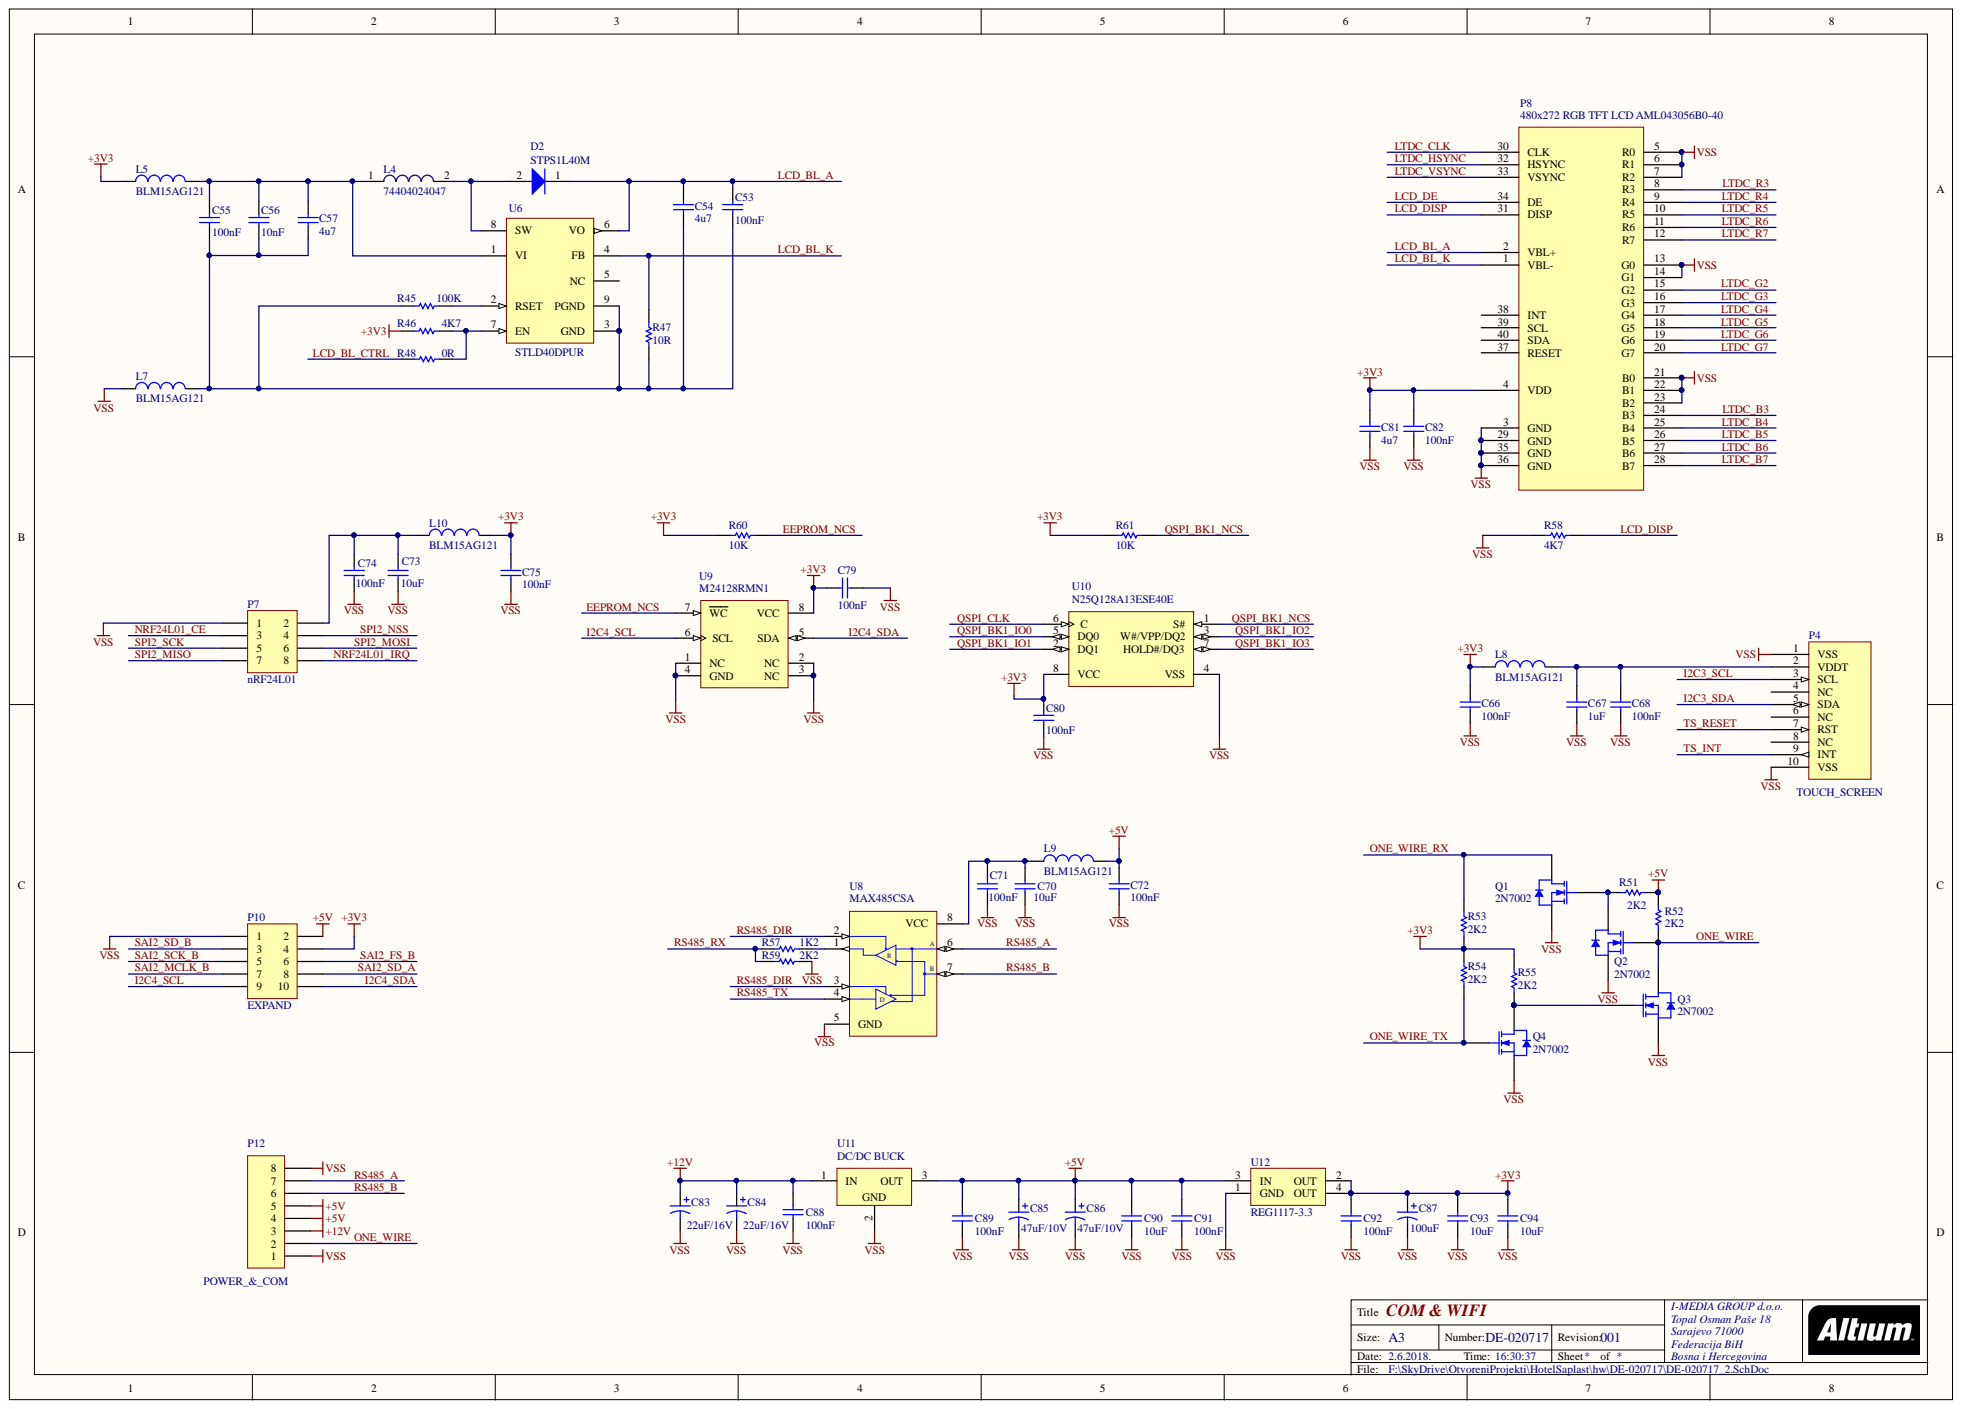
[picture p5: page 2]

COM & WIFI Title | I-MEDIA GROUP d.o.o. Topal Osman Paše 18 Sarajevo 71000 Federacija BiH Bosna i Hercegovina

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

F:\SkyDrive\OtvoreniProjekti\HotelSaplast\hw\DE-020717\DE-020717_2.SchDoc

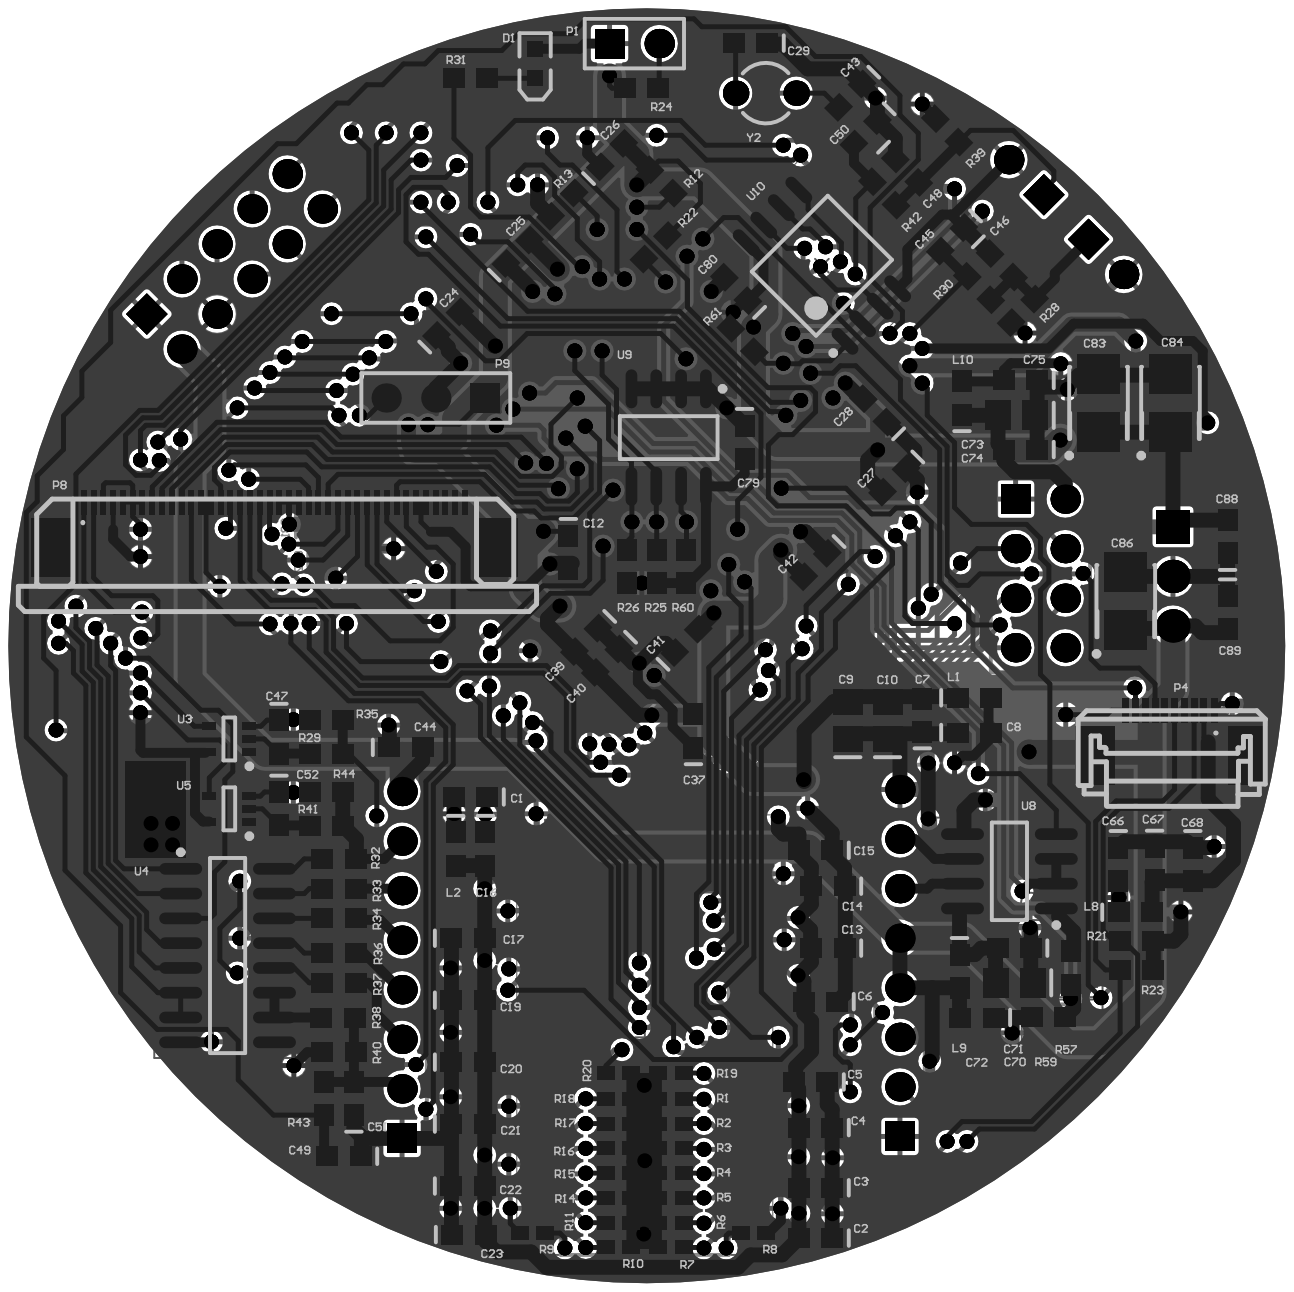
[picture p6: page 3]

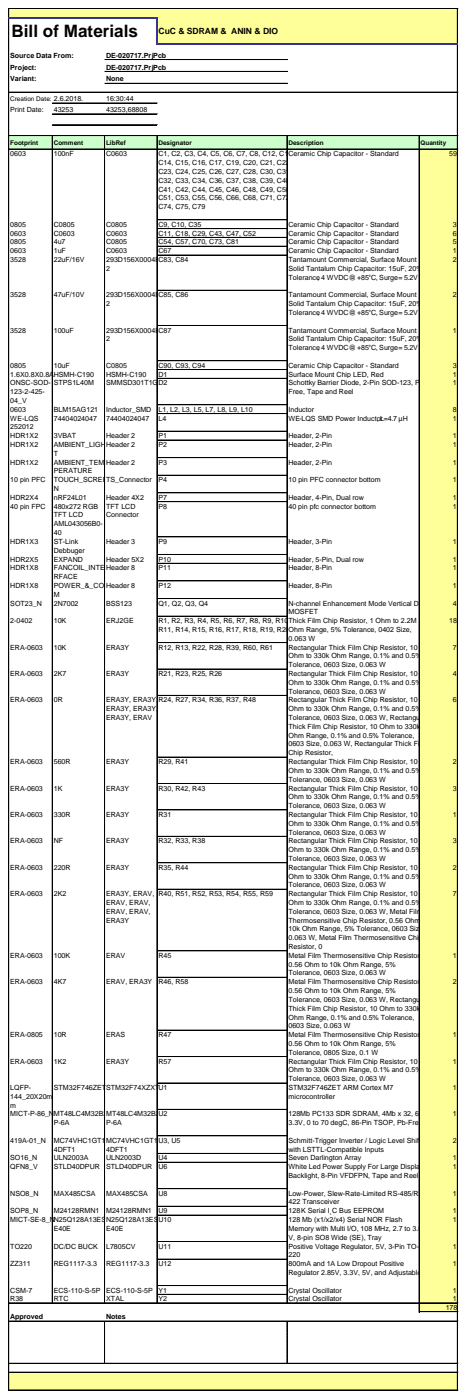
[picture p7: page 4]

Footprint | Comment | LibRef | Designator | Description | Quantity

Solid Tantalum Chip Capacitor: 15uF, 20%
Tolerance, 4 WVDC @ +85°C, Surge = 5.2V

Free, Tape and Reel

MOSFET
Thick Film Chip Resistor, 1 Ohm to 2.2M
Ohm Range, 5% Tolerance, 0402 Size,

Ohm to 330k Ohm Range, 0.1% and 0.5%
Tolerance, 0603 Size, 0.063 W

Tolerance, 0603 Size, 0.063 W, Rectangular
Thick Film Chip Resistor, 10 Ohm to 330k
Ohm Range, 0.1% and 0.5% Tolerance,
0603 Size, 0.063 W, Rectangular Thick Film
Chip Resistor,

Tolerance, 0603 Size, 0.063 W, Metal Film
Thermosensitive Chip Resistor, 0.56 Ohm
10k Ohm Range, 5% Tolerance, 0603 Siz
0.063 W, Metal Film Thermosensitive Chip
Resistor, 0

0.56 Ohm to 10k Ohm Range, 5%

0603 Size, 0.063 W

Tolerance, 0805 Size, 0.1 W

3.3V, 0 to 70 degC, 86-Pin TSOP, Pb-Free

with LSTTL-Compatible Inputs

Backlight, 8-Pin VFDFPN, Tape and Reel

Memory with Multi I/O, 108 MHz, 2.7 to 3.6
V, 8-pin SO8 Wide (SE), Tray

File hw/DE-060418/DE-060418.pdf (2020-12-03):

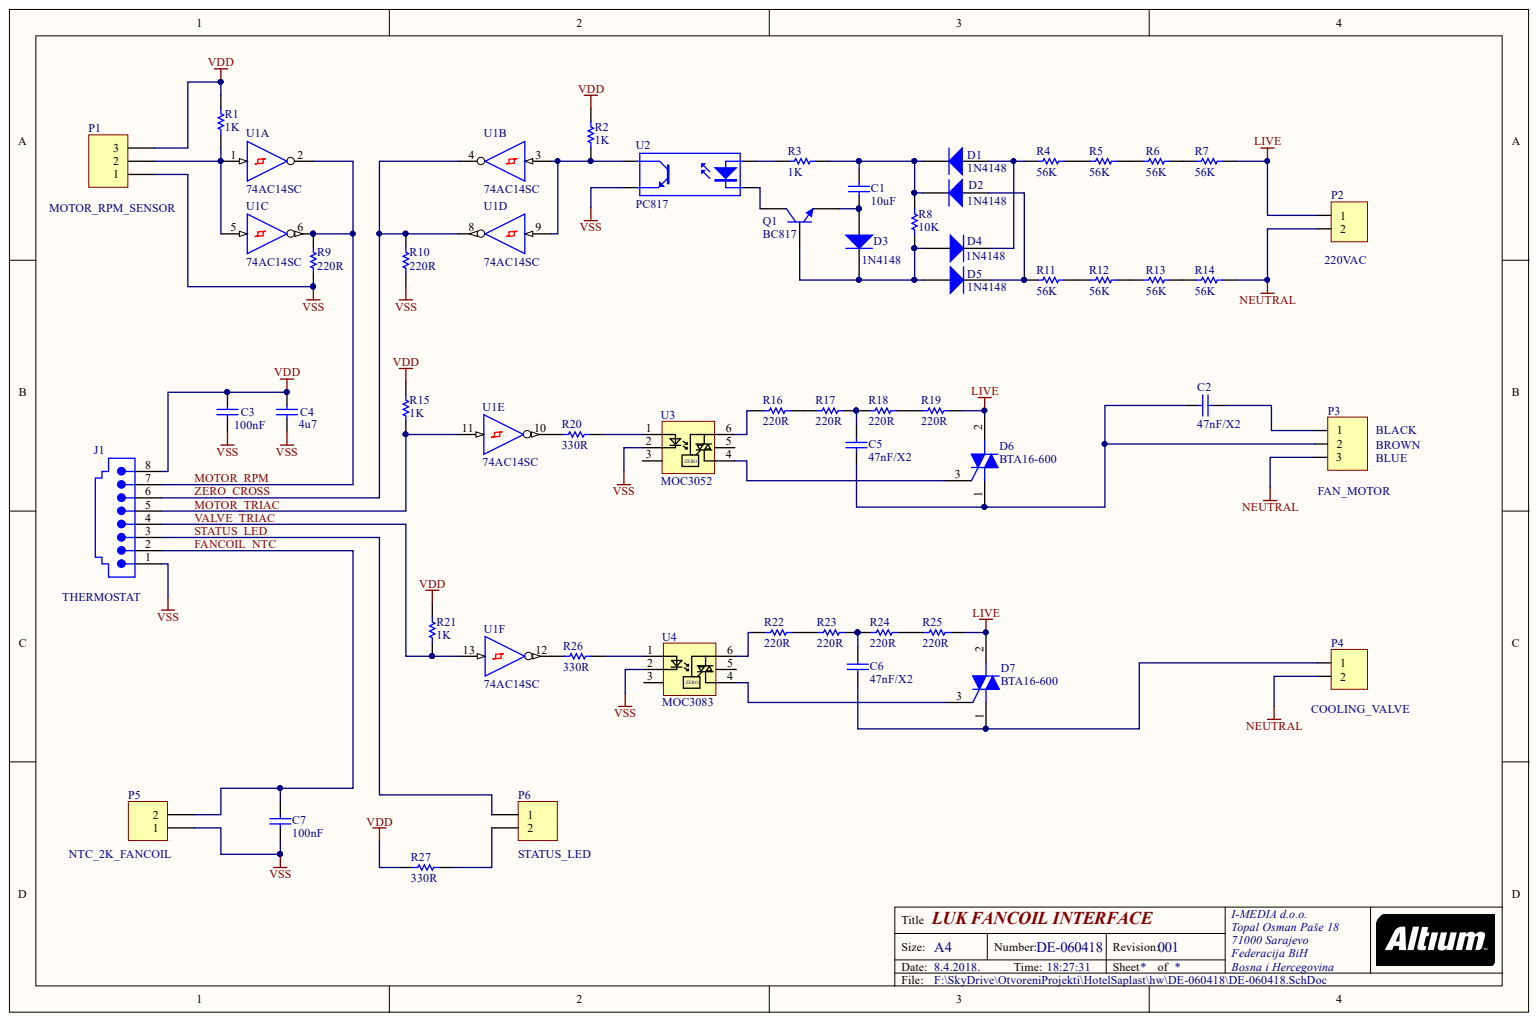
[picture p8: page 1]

74AC14SC | | R10 220R VSS VDD R15 1K

3 | STATUS_LED
2 | FANCOIL_NTC

LUK FANCOIL INTERFACE Title | I-MEDIA d.o.o. Topal Osman Paše 18 71000 Sarajevo Federacija BiH Bosna i Hercegovina

A4 Size: | DE-060418 Number: | 001 Revision:
Date: 8.4.2018. Time: 18:27:31 | | Sheet * of *

F:\SkyDrive\OtvoreniProjekti\HotelSaplast\hw\DE-060418\DE-060418.SchDoc
File:

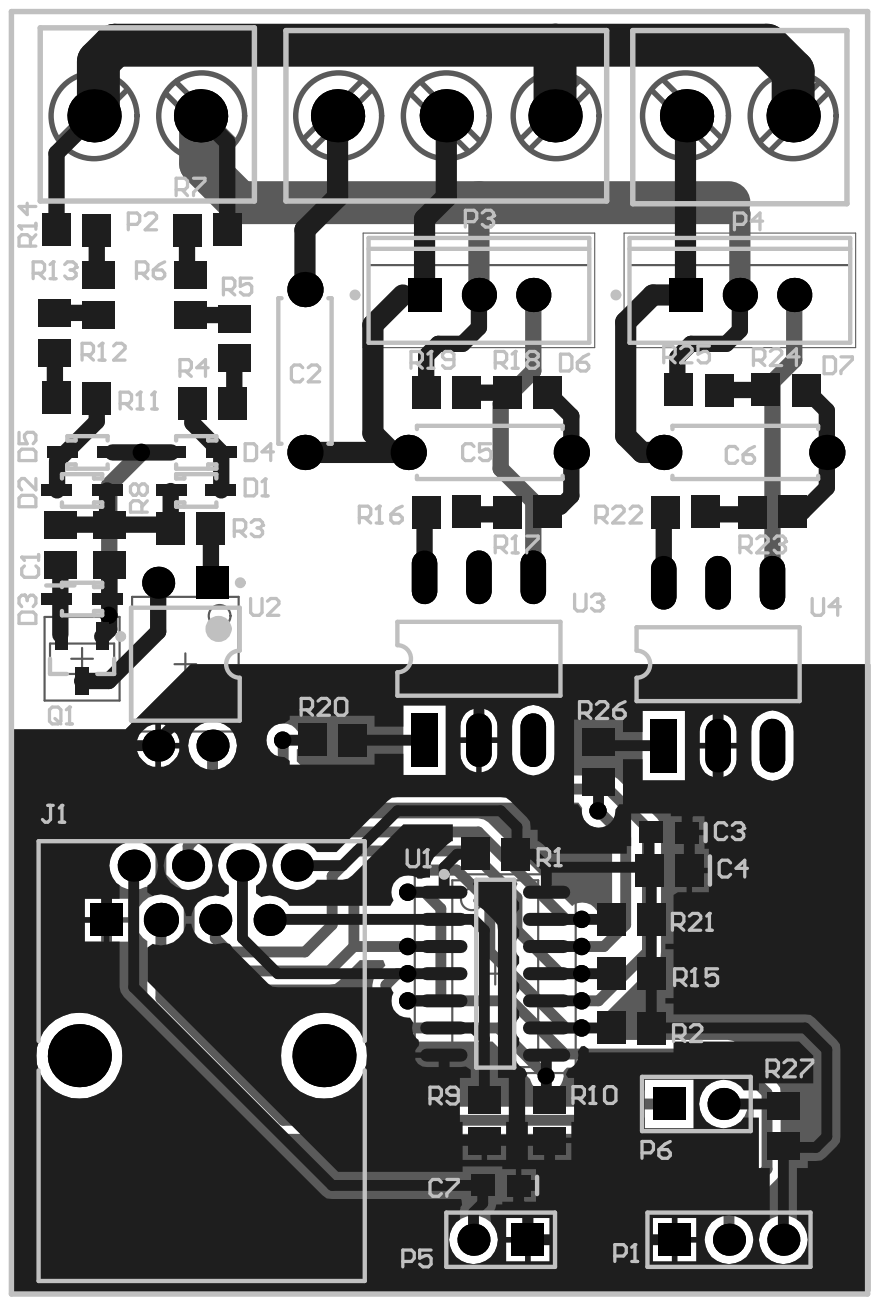
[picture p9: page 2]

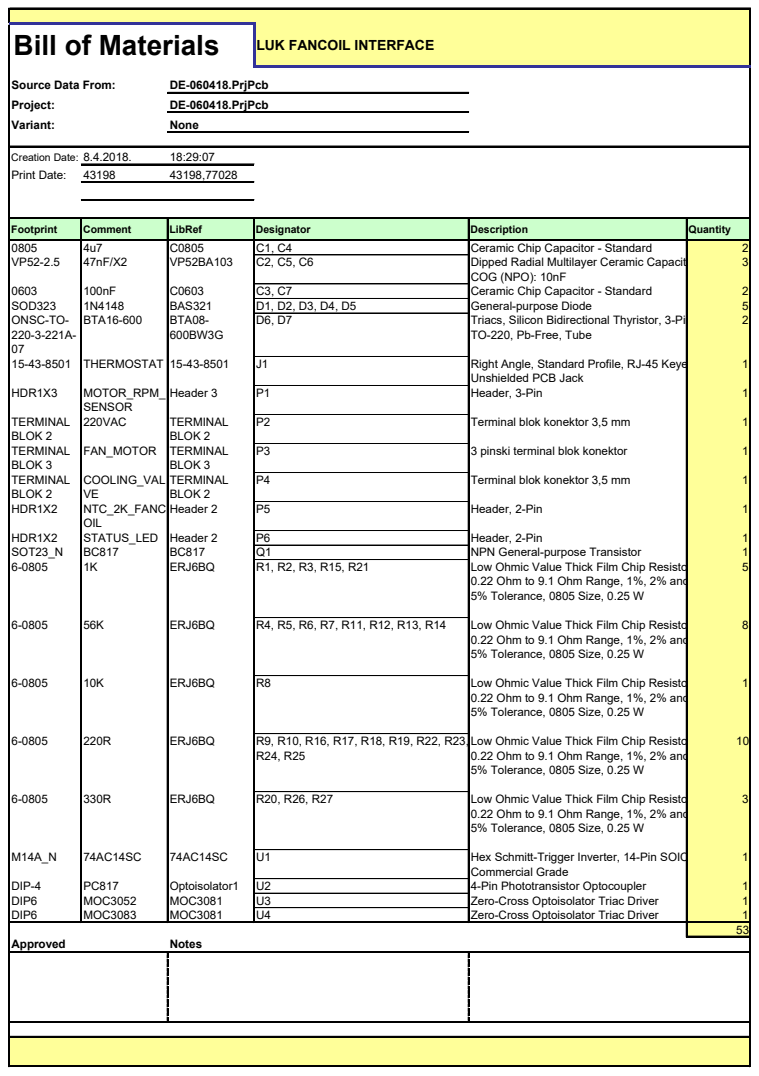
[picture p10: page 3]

TO-220, Pb-Free, Tube

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

Low Ohmic Value Thick Film Chip Resistor,

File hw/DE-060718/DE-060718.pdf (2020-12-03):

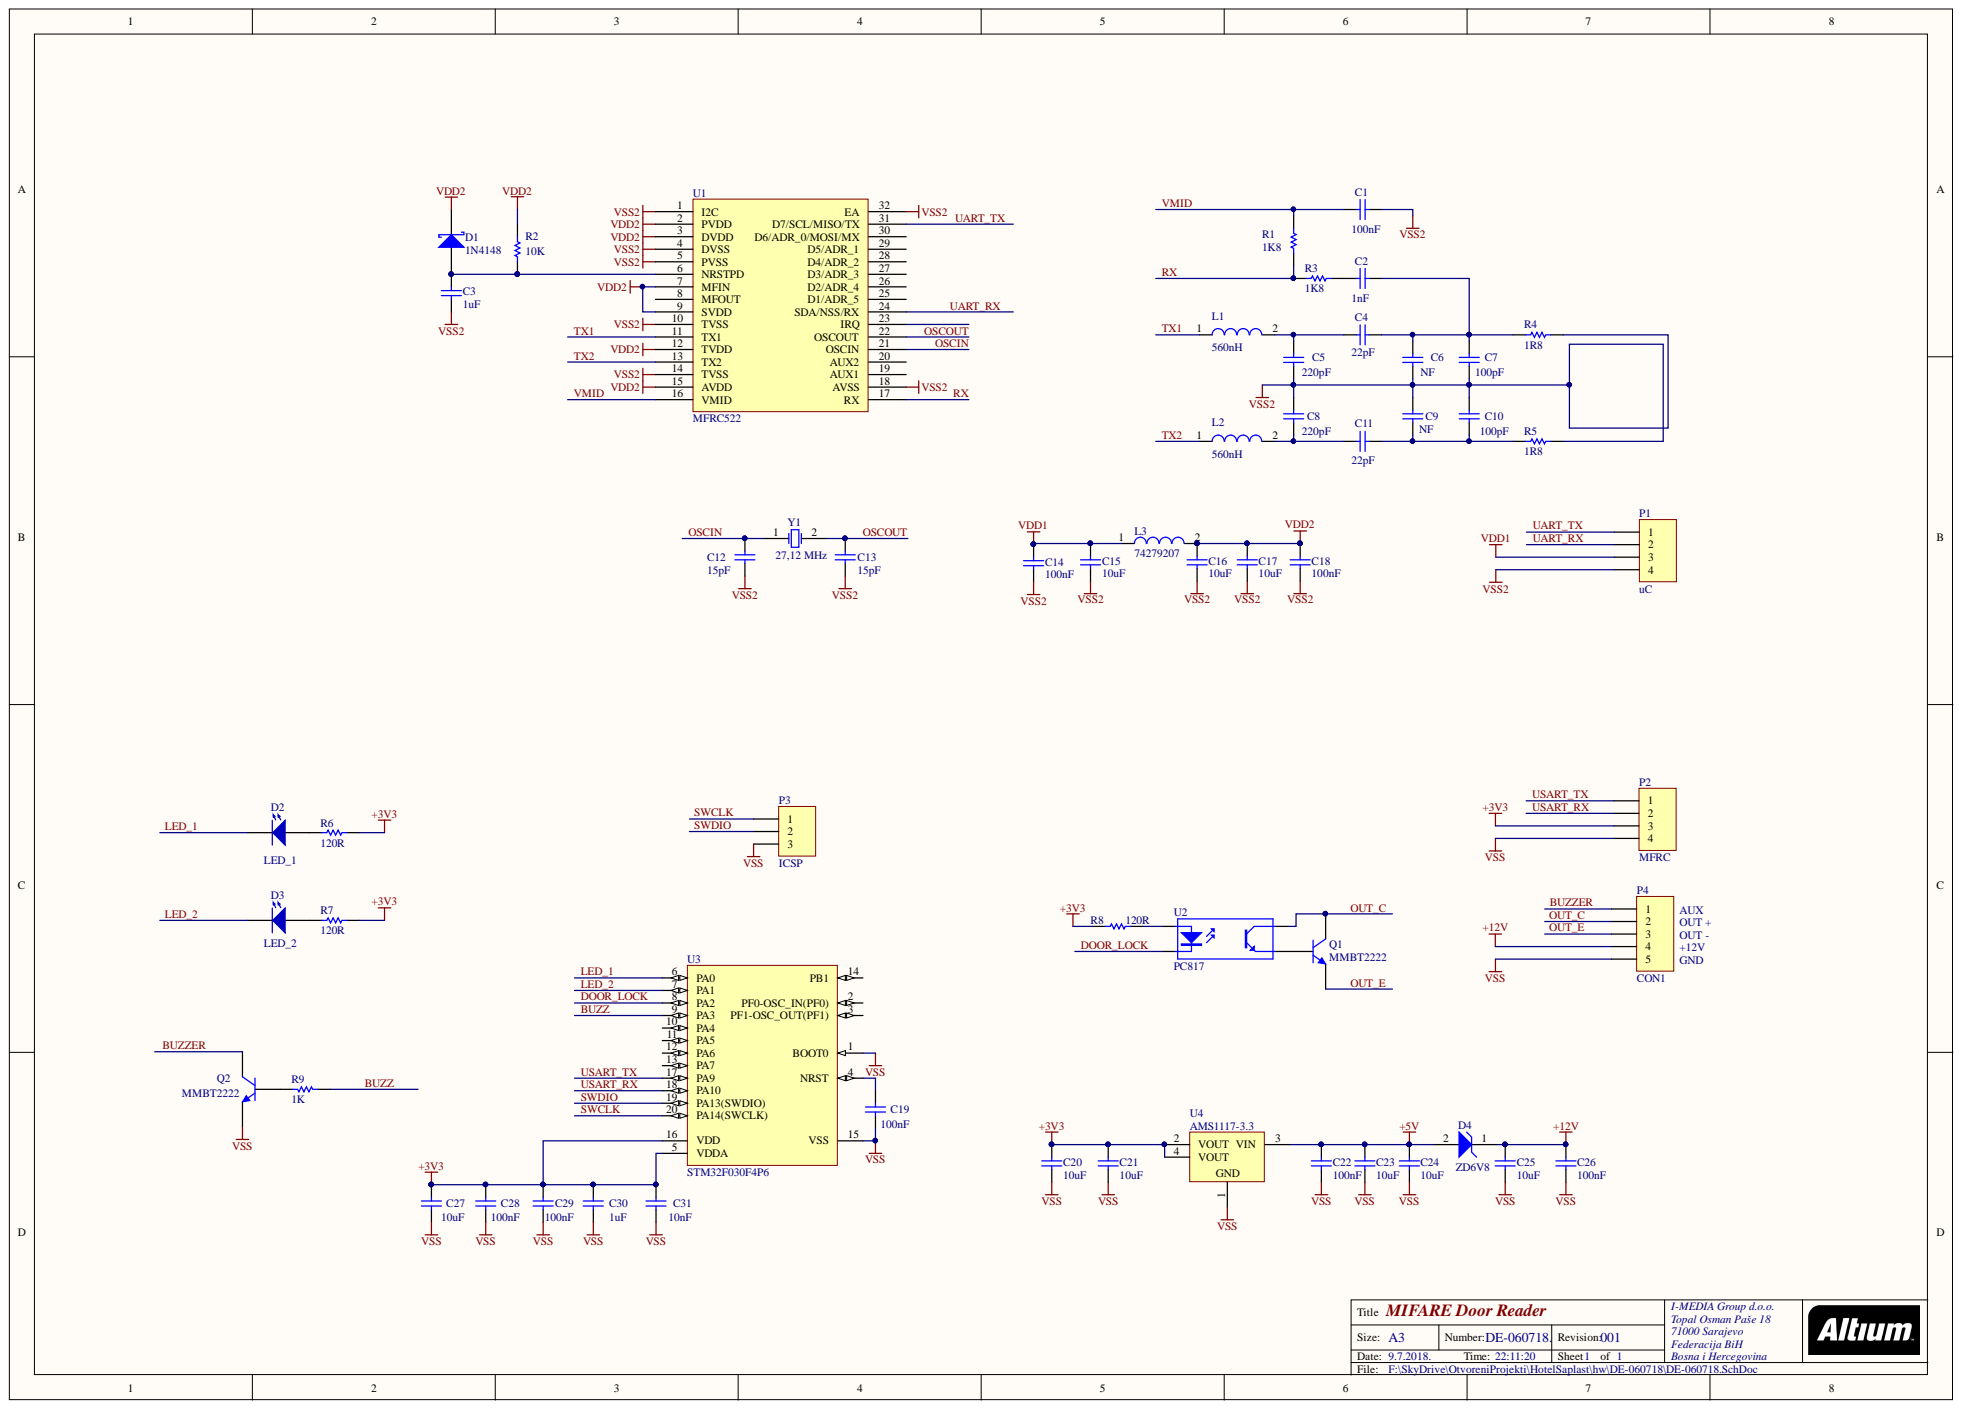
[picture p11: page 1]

MFIN 7
MFOUT 8

MIFARE Door Reader Title | I-MEDIA Group d.o.o. Topal Osman Paše 18 71000 Sarajevo Federacija BiH Bosna i Hercegovina

Size: A3 | Number: DE-060718. | Revision: 001
Date: 9.7.2018. Time: 22:11:20 | | Sheet 1 of 1

F:\SkyDrive\OtvoreniProjekti\HotelSaplast\hw\DE-060718\DE-060718.SchDoc

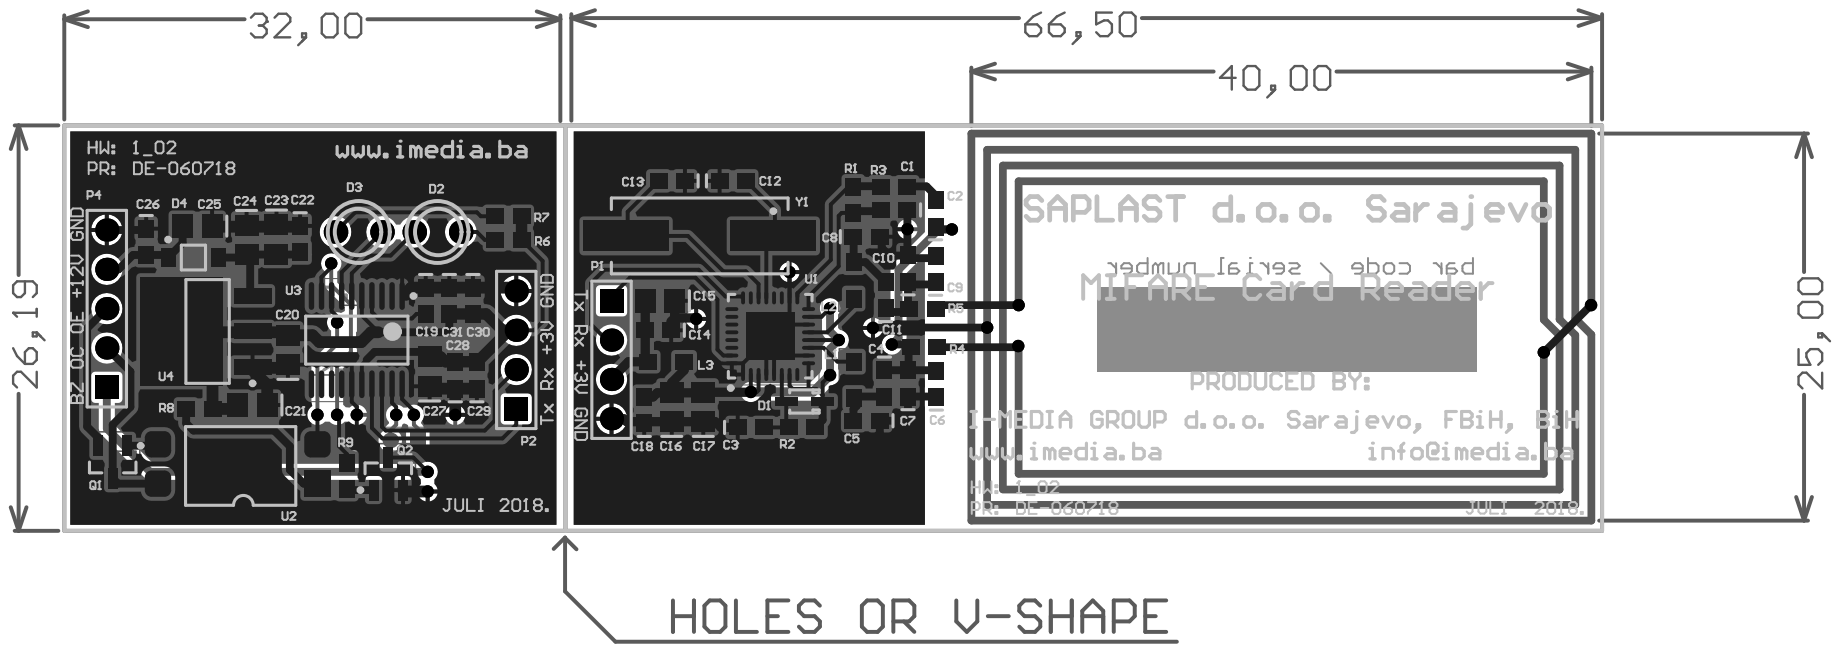
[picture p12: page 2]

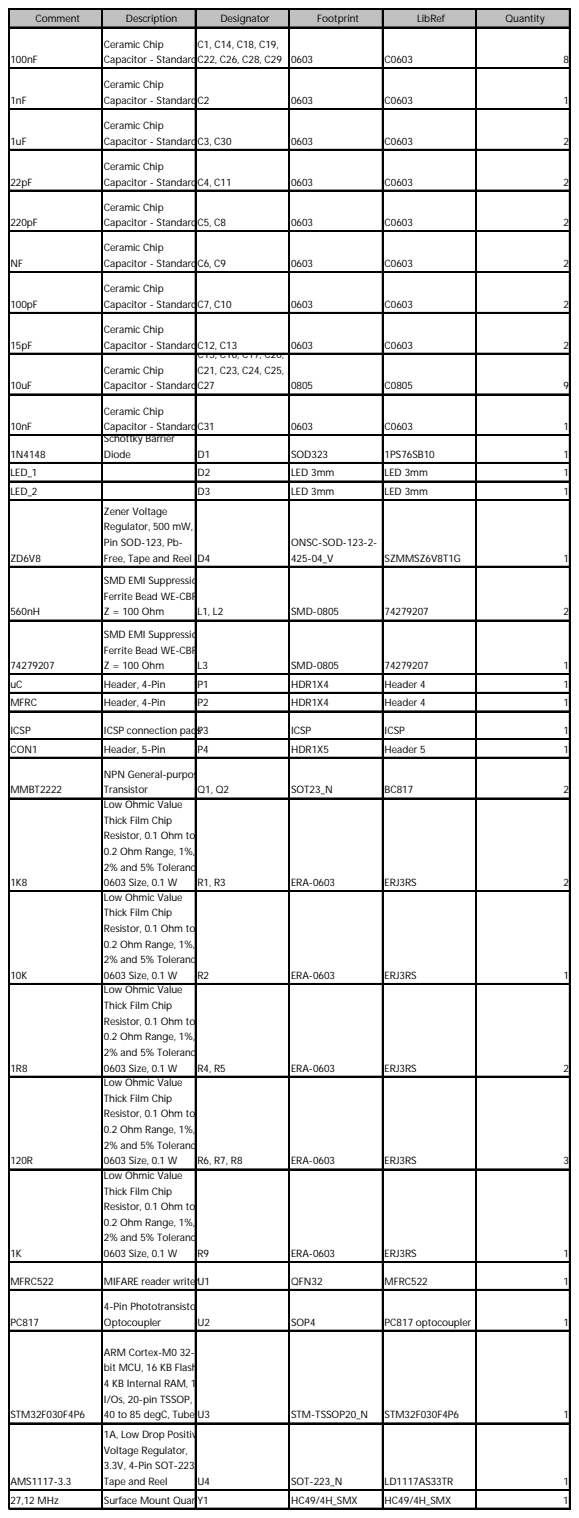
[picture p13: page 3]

Comment | Description | Designator | Footprint | LibRef | Quantity

100nF | Ceramic Chip Capacitor - Standard | C1, C14, C18, C19, C22, C26, C28, C29 | 0603 | C0603 | 8

1nF | Ceramic Chip Capacitor - StandardC2 | | 0603 | C0603 | 1

1uF | Ceramic Chip Capacitor - StandardC3, C30 | | 0603 | C0603 | 2

22pF | Ceramic Chip Capacitor - StandardC4, C11 | | 0603 | C0603 | 2

220pF | Ceramic Chip Capacitor - StandardC5, C8 | | 0603 | C0603 | 2

NF | Ceramic Chip Capacitor - StandardC6, C9 | | 0603 | C0603 | 2

100pF | Ceramic Chip Capacitor - StandardC7, C10 | | 0603 | C0603 | 2

15pF | Ceramic Chip Capacitor - StandardC12, C13 | | 0603 | C0603 | 2

10uF | Ceramic Chip Capacitor - Standard | C15, C16, C17, C20, C21, C23, C24, C25, C27 | 0805 | C0805 | 9

10nF | Ceramic Chip Capacitor - StandardC31 | | 0603 | C0603 | 1

1N4148 | Schottky Barrier Diode | D1 | SOD323 | 1PS76SB10 | 1

LED_1 | | D2 | LED 3mm | LED 3mm | 1
LED_2 | | D3 | LED 3mm | LED 3mm | 1

ZD6V8 | Zener Voltage Regulator, 500 mW, 2-Pin SOD-123, Pb-Free, Tape and Reel | D4 | ONSC-SOD-123-2-425-04_V | SZMMSZ6V8T1G | 1

560nH | SMD EMI Suppression Ferrite Bead WE-CBF, Z = 100 Ohm | L1, L2 | SMD-0805 | 74279207 | 2

74279207 | SMD EMI Suppression Ferrite Bead WE-CBF, Z = 100 Ohm | L3 | SMD-0805 | 74279207 | 1

uC | Header, 4-Pin | P1 | HDR1X4 | Header 4 | 1
MFRC | Header, 4-Pin | P2 | HDR1X4 | Header 4 | 1

ICSP | ICSP connection padsP3 | | ICSP | ICSP | 1
CON1 | Header, 5-Pin | P4 | HDR1X5 | Header 5 | 1

MMBT2222 | NPN General-purpose Transistor | Q1, Q2 | SOT23_N | BC817 | 2

1K8 | Low Ohmic Value Thick Film Chip Resistor, 0.1 Ohm to 0.2 Ohm Range, 1%, 2% and 5% Tolerance, 0603 Size, 0.1 W | R1, R3 | ERA-0603 | ERJ3RS | 2

10K | Low Ohmic Value Thick Film Chip Resistor, 0.1 Ohm to 0.2 Ohm Range, 1%, 2% and 5% Tolerance, 0603 Size, 0.1 W | R2 | ERA-0603 | ERJ3RS | 1

1R8 | Low Ohmic Value Thick Film Chip Resistor, 0.1 Ohm to 0.2 Ohm Range, 1%, 2% and 5% Tolerance, 0603 Size, 0.1 W | R4, R5 | ERA-0603 | ERJ3RS | 2

120R | Low Ohmic Value Thick Film Chip Resistor, 0.1 Ohm to 0.2 Ohm Range, 1%, 2% and 5% Tolerance, 0603 Size, 0.1 W | R6, R7, R8 | ERA-0603 | ERJ3RS | 3

1K | Low Ohmic Value Thick Film Chip Resistor, 0.1 Ohm to 0.2 Ohm Range, 1%, 2% and 5% Tolerance, 0603 Size, 0.1 W | R9 | ERA-0603 | ERJ3RS | 1

MFRC522 | MIFARE reader writerU1 | | QFN32 | MFRC522 | 1

PC817 | 4-Pin Phototransistor Optocoupler | U2 | SOP4 | PC817 optocoupler | 1

STM32F030F4P6 | ARM Cortex-M0 32-bit MCU, 16 KB Flash, 4 KB Internal RAM, 15 I/Os, 20-pin TSSOP, -40 to 85 degC, Tube U3 | | STM-TSSOP20_N | STM32F030F4P6 | 1

AMS1117-3.3 | 1A, Low Drop Positive Voltage Regulator, 3.3V, 4-Pin SOT-223, Tape and Reel | U4 | SOT-223_N | LD1117AS33TR | 1

27,12 MHz | Surface Mount Quartz Crystal Y1 | | HC49/4H_SMX | HC49/4H_SMX | 1

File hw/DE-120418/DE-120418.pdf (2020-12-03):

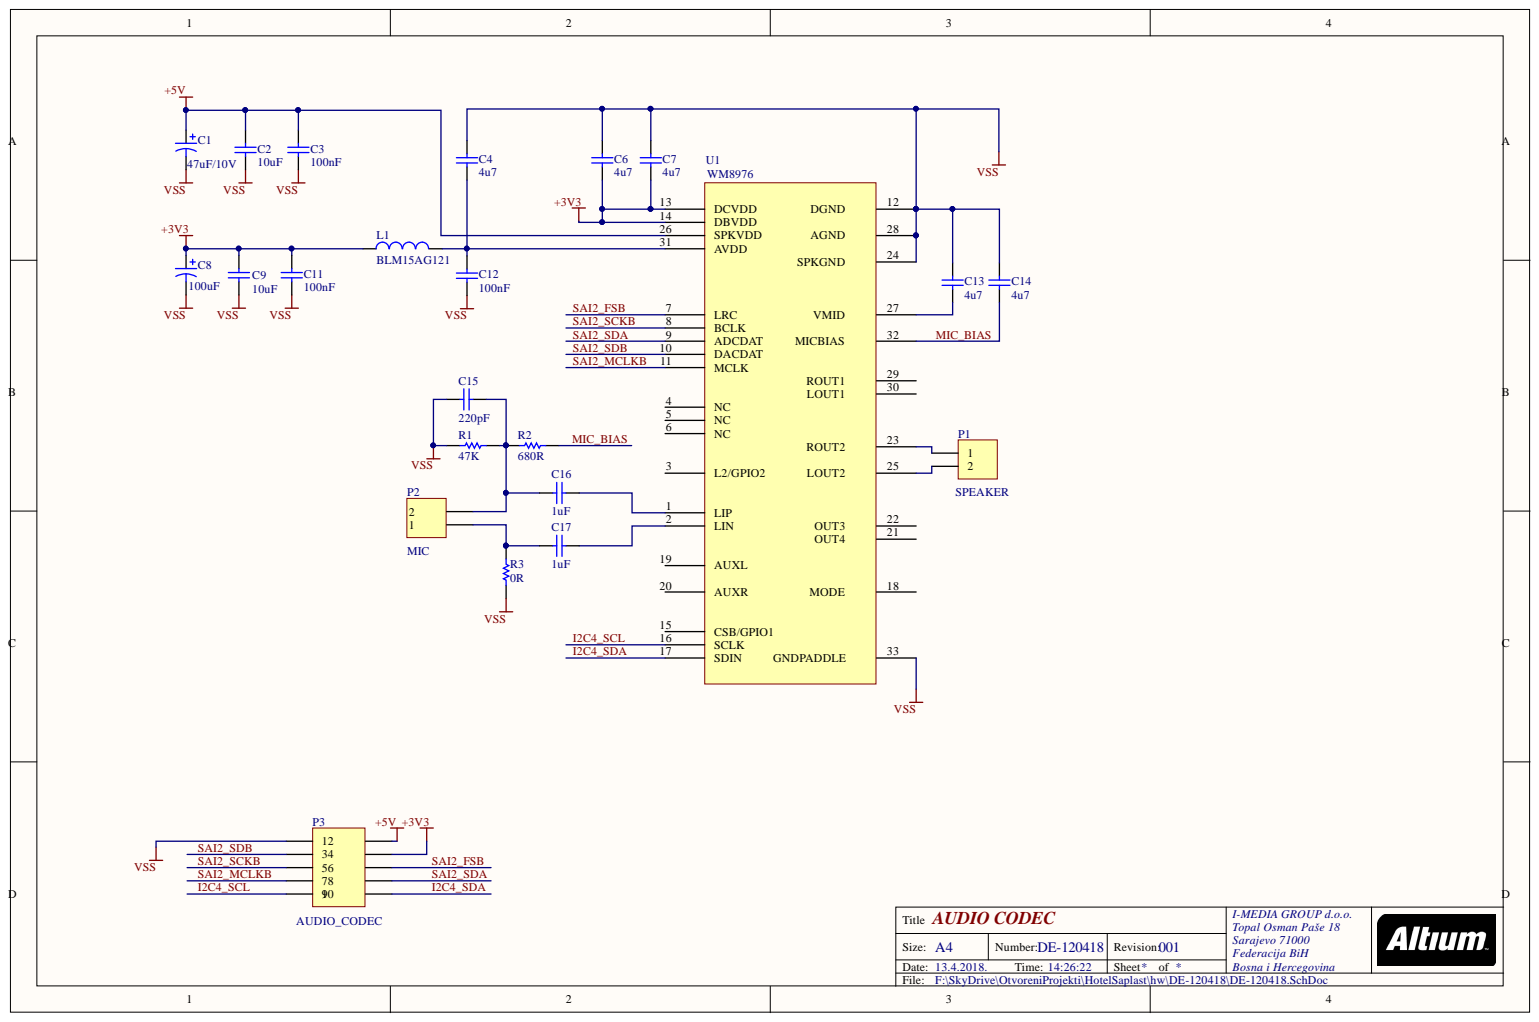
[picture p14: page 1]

AUDIO CODEC Title | I-MEDIA GROUP d.o.o. Topal Osman Paše 18 Sarajevo 71000 Federacija BiH Bosna i Hercegovina

A4 Size: | DE-120418 Number: | 001 Revision:
Date: 13.4.2018. Time: 14:26:22 | | Sheet * of *

F:\SkyDrive\OtvoreniProjekti\HotelSaplast\hw\DE-120418\DE-120418.SchDoc

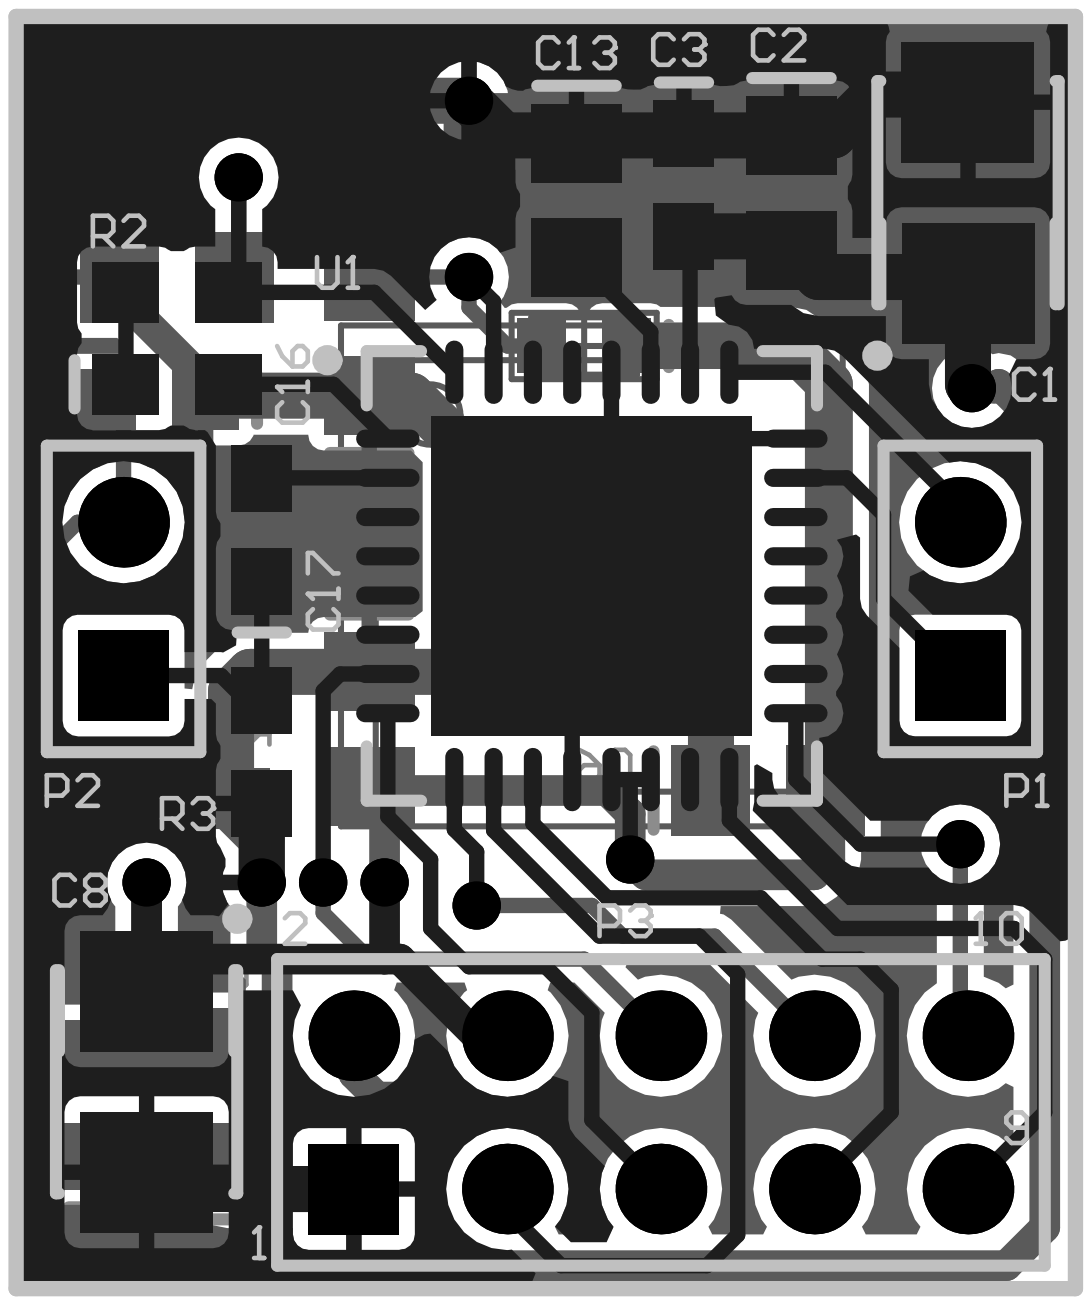
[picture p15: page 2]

Bill of Materials | AUDIO CODEC
Source Data From: | DE-120418.PrjPcb
Project: | | DE-120418.PrjPcb
Variant: | | None
Creation Date: 13.4.2018. | 14:26:23
Print Date: | 43203 | 43203,60172
Footprint | Comment | LibRef | Designator | Description | Quantity
| | | | | 1
3528 | 47uF/10V | 293D156X0004B
2
| | | C1 | Tantamount Commercial, Surface Mount
| | | | Solid Tantalum Chip Capacitor: 15uF, 20%
| | | | Tolerance, 4 WVDC @ +85°C, Surge = 5.2V
0805 | 10uF | C0805 | C2, C9 | Ceramic Chip Capacitor - Standard | 2
0603 | 100nF | C0603 | C3, C11, C12 | Ceramic Chip Capacitor - Standard | 3
0805 | 4u7 | C0805 | C4, C6, C7, C13, C14 | Ceramic Chip Capacitor - Standard | 5
3528 | 100uF | 293D156X0004B
| | 2 | C8 | Tantamount Commercial, Surface Mount
| | | | Solid Tantalum Chip Capacitor: 15uF, 20%
| | | | Tolerance, 4 WVDC @ +85°C, Surge = 5.2V | 1
0603 | 220pF | C0603 | C15 | Ceramic Chip Capacitor - Standard | 1
0603 | 1uF | C0603 | C16, C17 | Ceramic Chip Capacitor - Standard | 2
INDC1608L | BLM15AG121 | Inductor_SMD | L1 | Inductor | 1
HDR1X2 | SPEAKER | Header 2 | P1 | Header, 2-Pin | 1
HDR1X2 | MIC | Header 2 | P2 | Header, 2-Pin | 1
HDR2X5 | AUDIO_CODECHeader 5X2 | P3 | Header, 5-Pin, Dual row | 1
ERA-0603 | 47K | ERAV | R1 | Metal Film Thermosensitive Chip Resistor,
| | | | 0.56 Ohm to 10k Ohm Range, 5%
| | | | Tolerance, 0603 Size, 0.063 W | 1
ERA-0603 | 680R | ERAV | R2 | Metal Film Thermosensitive Chip Resistor, 0.56 Ohm to 10k Ohm Range, 5% Tolerance, 0603 Size, 0.063 W
1
ERA-0603 | 0R | ERAV | R3 | Metal Film Thermosensitive Chip Resistor, 0.56 Ohm to 10k Ohm Range, 5% Tolerance, 0603 Size, 0.063 W
1
QFN32_N | WM8976 | WM8976 | U1 | Stereo CODEC with speaker driver | 1
| | | | | 23
Approved | | Notes

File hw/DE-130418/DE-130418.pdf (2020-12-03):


FANCOIL INTERFACE T i t l e | I-MEDIA G R O UP d.o.o . Top a l O s m a n P a še 1 8 S a r ajevo 7 1 0 0 0 Feder acij a B i H B o s n a i Herceg ovi n a

A4 Size: | DE-1 3 0 4 1 8 N umber: | 0 0 1 Rev i s i o n :
Date: 1 3.4.2 0 1 8 . T ime: 1 6 : 2 3 : 0 8 | | Sheet * o f *



TO-220, Pb-Free, Tube

0.56 Ohm to 10k Ohm Range, 5%
Tolerance, 0805 Size, 0.1 W

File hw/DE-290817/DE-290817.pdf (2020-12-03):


Microcontroller - Memory - Display Title | I-MEDIA GROUP d.o.o. Topal Osman Paše 18 71000 Sarajevo Federacija BiH Bosna i Hercegovina

Size: A3 | Number: 1 | Revision: 001
Date: 20.09.2017. Time: 17:37:23 | | Sheet of 2

C:\Users\eldar\Desktop\HotelRoomAccessControlUnit\hw\DE-290817_01.SchDoc


DIN6
DIN7

Digital I/O - Power - Com Title | I-MEDIA GROUP d.o.o. Topal Osman Paše 18 71000 Sarajevo Federacija BiH Bosna i Hercegovina

Size: A3 | Number: 2 | Revision: 001
20.09.2017. Time: 17:37:23 | | Sheet of 2

C:\Users\eldar\Desktop\HotelRoomAccessControlUnit\hw\DE-290817_02.SchDoc


Mifare Rea der Writer T i t l e | I-MEDIA G R O UP d.o.o . Top a l O s m a n P a še 1 8 7 1 0 0 0 S a r ajevo Feder acij a B i H B o s n a i Herceg ovi n a

A4 Size: | * N umber: | 0 0 1 Rev i s i o n :

0.0 9.2 . T ime: : : | | Sheet * o f *



Footprint | Comment | LibRef | Designator | Description | Quantity

Diode, Schottky Barrier Diode, General-
purpose Diode

Free, Tape and Reel

Transistor, N-channel Enhancement Mode
Vertical D-MOSFET, N-channel
Enhancement Mode Vertical D-MOSFET, N-
channel Enhancement Mode Vertical D-
MOSFET, N-channel Enhancement Mode
Vertical D-MOSFET

Channel, 8-Pin SOIC, Pb-Free, Tape and
Reel

0.56 Ohm to 10k Ohm Range, 5%
Tolerance, 0603 Size, 0.063 W

Metal Film Thermosensitive Chip Resistor,

Resistor, 4.7 Ohm to 1k Ohm Range, 2%
and 5% Tolerance, 0.166 W

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

Proximity Detection & Signal Guard

20 KB Internal RAM, 37 I/Os, 48-pin LQFP, -
40 to 85 degC, Tray

KHz 3A Step-Down Voltage Regulator, 5-pin

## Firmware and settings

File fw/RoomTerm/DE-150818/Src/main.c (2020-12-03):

/**
 ******************************************************************************
 * File Name          : main.c
 * Date               : 10.3.2018.
 * Description        : Hotel Room Thermostat Program Code
 ******************************************************************************
 *
 *
 ******************************************************************************
 */


/* Includes ------------------------------------------------------------------*/
#include "WM.h"
#include "GUI.h"
#include <math.h>
#include "main.h"
#include "common.h"
#include "display.h"
#include "one_wire.h"
#include "thermostat.h"
#include "stm32746g.h"
#include "stm32746g_ts.h"
#include "stm32746g_qspi.h"
#include "stm32746g_sdram.h"
#include "stm32746g_eeprom.h"


/* Imported Type  ------------------------------------------------------------*/
/* Imported Variable  --------------------------------------------------------*/
/* Imported Function  --------------------------------------------------------*/
/* Private Type --------------------------------------------------------------*/
ADC_HandleTypeDef hadc3;
UART_HandleTypeDef huart2;
TIM_HandleTypeDef htim3;
TIM_HandleTypeDef htim9;
I2C_HandleTypeDef hi2c4;
I2C_HandleTypeDef hi2c3;
LTDC_HandleTypeDef hltdc;
DMA2D_HandleTypeDef hdma2d;
CRC_HandleTypeDef hcrc;
RTC_HandleTypeDef hrtc;
RTC_TimeTypeDef time;
RTC_DateTypeDef date;
#ifndef	USE_DEBUGGER
IWDG_HandleTypeDef hiwdg;
#endif


/* Private Define ------------------------------------------------------------*/
#define TOUCH_SCREEN_UPDATE_TIME			25U     // 5ms touch screen update period
#define TOUCH_SCREEN_LAYER                  1U      // touch screen layer event
#define AMBIENT_NTC_RREF                    10000U  // 10k NTC value of at 25 degrees
#define AMBIENT_NTC_B_VALUE                 3977U   // NTC beta parameter
#define AMBIENT_NTC_PULLUP                  10000U	// 10k pullup resistor
#define FANCOIL_NTC_RREF                    2000U  	// 2k fancoil NTC value of at 25 degrees
#define FANCOIL_NTC_B_VALUE                 3977U   // NTC beta parameter
#define FANCOIL_NTC_PULLUP                  2200U	// 2k2 pullup resistor
#define ADC_READOUT_PERIOD                  234U    // 89 ms ntc conversion rate
#define FAN_CONTROL_LOOP_PERIOD			    200U    // fan speed control loop 
#define BUZZER_CLICK_TIME                   20U     // single 50 ms tone when button pressed
#define BUZZER_SHORT_TIME                   100U    // 100 ms buzzer activ then repeat pause  
#define BUZZER_MIDDLE_TIME                  500U    // 500 ms buzzer activ then repeat pause
#define BUZZER_LONG_TIME                    1000U   // 1 s buzzer activ then repeat pause
#define TRIAC_ON_PULSE                      5U      // 500 us triac fire pulse duration
#define SYSTEM_STARTUP_TIME                 12345U  // 12,5s system startup config check


/* Private Variable ----------------------------------------------------------*/
__IO uint32_t sys_flags;
__IO uint32_t fan_rpm_pulse;

uint16_t rs485_interface_address;
uint32_t thermostat_flags_memo;
uint8_t buzzer_signal_time;
uint8_t buzzer_signal_id;

static uint32_t triac_timer;
static uint32_t triac_on_time;

/* Constants ----------------------------------------------------------------*/
const char sys_info_hw[] = {"HW: DE020717"};    // hardware version
const char sys_info_fw[] = {"FW: RT200119"};    // firmware version

const uint8_t RTC_Months[2][12] = {
	{31U, 28U, 31U, 30U, 31U, 30U, 31U, 31U, 30U, 31U, 30U, 31U},	/* Not leap year */
	{31U, 29U, 31U, 30U, 31U, 30U, 31U, 31U, 30U, 31U, 30U, 31U}};	/* Leap year */

const uint32_t baud_rate[] ={ 2400U,   4800U,   9600U,  19200U,  38400U,
                             57600U, 115200U, 230400U, 460800U, 921600U};


/* Private Macro -------------------------------------------------------------*/
#define RTC_LEAP_YEAR(year)             ((((year) % 4U == 0U) && ((year) % 100U != 0U)) || ((year) % 400U == 0U))
#define RTC_DAYS_IN_YEAR(x)             RTC_LEAP_YEAR(x) ? 366U : 365U
#define RTC_BCD2BIN(x)                  ((((x) >> 4U) & 0x0FU) * 10U + ((x) & 0x0FU))
#define RTC_CHAR2NUM(x)                 ((x) - '0')
#define RTC_CHARISNUM(x)                ((x) >= '0' && (x) <= '9')


/* Private Function Prototype ------------------------------------------------*/
static void MPU_Config(void);
static void CACHE_Config(void);
static void SystemClock_Config(void);
#ifndef	USE_DEBUGGER
void MX_IWDG_Init(void);
#endif
static void MX_GPIO_Init(void);
static void MX_GPIO_DeInit(void);
static void MX_CRC_Init(void);
static void MX_CRC_DeInit(void);
static void MX_RTC_Init(void);
static void MX_RTC_DeInit(void);
static void MX_TIM3_Init(void);
static void MX_TIM3_DeInit(void);
static void MX_TIM9_Init(void);
static void MX_TIM9_DeInit(void);
static void MX_UART2_Init(void);
static void MX_UART2_DeInit(void);
static void MX_ADC3_Init(void);
static void MX_ADC3_DeInit(void);
static void ADC3_Read(void);
static void RAM_Init(void);
static void BUZZER_Service(void);
static void TOUCH_SCREEN_Service(void);
static void RESTART_Init(void);
static float AMBIENT_NTC_GetTemperature(uint16_t adc_value);
static float FANCOIL_NTC_GetTemperature(uint16_t adc_value);


/* Program Code  -------------------------------------------------------------*/
int main(void)
{
	MPU_Config();
	CACHE_Config();
	HAL_Init(); 
	SystemClock_Config();
#ifndef	USE_DEBUGGER
	MX_IWDG_Init();
#endif	
    MX_CRC_Init();
	MX_RTC_Init();
	MX_ADC3_Init();
	MX_UART2_Init();
	MX_TIM3_Init();
	MX_TIM9_Init();
	MX_GPIO_Init();
	MX_QSPI_Init();
    BSP_EEPROM_Init();
    TOUCH_SCREEN_Init(480, 272);
	SDRAM_Init();
    RAM_Init();
    THERMOSTAT_Init();
	DISPLAY_Init();
	ONEWIRE_Init();
    FAN_SetControlType(fan_control_type);
#ifndef	USE_DEBUGGER
	HAL_IWDG_Refresh(&hiwdg);
#endif

	while(1)
	{
        ADC3_Read();
		THERMOSTAT_Service();
        TOUCH_SCREEN_Service();
		DISPLAY_Service();
        BUZZER_Service();
#ifndef	USE_DEBUGGER
        HAL_IWDG_Refresh(&hiwdg);
#endif
	}
}


void RTC_GetDateTime(RTC_t* data, uint32_t format) 
{
	uint32_t unix;

	/* Get time */
	if (format == RTC_FORMAT_BIN) 
	{
		HAL_RTC_GetTime(&hrtc, &time, RTC_FORMAT_BIN);
	} 
	else 
	{
		HAL_RTC_GetTime(&hrtc, &time, RTC_FORMAT_BCD);
	}
	
	/* Format hours */
	data->hours = time.Hours;
	data->minutes = time.Minutes;
	data->seconds = time.Seconds;
	
	/* Get subseconds */
	data->subseconds = RTC->SSR;
	
	/* Get date */
	if (format == RTC_FORMAT_BIN) 
	{
		HAL_RTC_GetDate(&hrtc, &date, RTC_FORMAT_BIN);
	} 
	else 
	{
		HAL_RTC_GetDate(&hrtc, &date, RTC_FORMAT_BCD);
	}
	
	/* Format date */
	data->year = date.Year;
	data->month = date.Month;
	data->date = date.Date;
	data->day = date.WeekDay;
	
	/* Calculate unix offset */
	unix = RTC_GetUnixTimeStamp(data);
	data->unix = unix;
}


uint32_t RTC_GetUnixTimeStamp(RTC_t* data) 
{
	uint32_t days = 0U, seconds = 0U;
	uint16_t i;
	uint16_t year = (uint16_t) (data->year + 2000U);
	
	/* Year is below offset year */
	if (year < RTC_OFFSET_YEAR) 
	{
		return 0U;
	}
	
	/* Days in back years */
	for (i = RTC_OFFSET_YEAR; i < year; i++) 
	{
		days += RTC_DAYS_IN_YEAR(i);
	}
	
	/* Days in current year */
	for (i = 1U; i < data->month; i++) 
	{
		days += RTC_Months[RTC_LEAP_YEAR(year)][i - 1U];
	}
	
	/* Day starts with 1 */
	days += data->date - 1U;
	seconds = days * RTC_SECONDS_PER_DAY;
	seconds += data->hours * RTC_SECONDS_PER_HOUR;
	seconds += data->minutes * RTC_SECONDS_PER_MINUTE;
	seconds += data->seconds;
	
	/* seconds = days * 86400; */
	return seconds;
}


void RTC_GetDateTimeFromUnix(RTC_t* data, uint32_t unix) 
{
	uint16_t year;
	
	/* Store unix time to unix in struct */
	data->unix = unix;
	/* Get seconds from unix */
	data->seconds = unix % 60U;
	/* Go to minutes */
	unix /= 60U;
	/* Get minutes */
	data->minutes = unix % 60U;
	/* Go to hours */
	unix /= 60U;
	/* Get hours */
	data->hours = unix % 24U;
	/* Go to days */
	unix /= 24U;
	
	/* Get week day */
	/* Monday is day one */
	data->day = (unix + 3U) % 7U + 1U;

	/* Get year */
	year = 1970U;
	while (1U) 
	{
		if (RTC_LEAP_YEAR(year)) 
		{
			if (unix >= 366U) 
			{
				unix -= 366U;
			} 
			else 
			{
				break;
			}
		} 
		else if (unix >= 365U) 
		{
			unix -= 365U;
		} 
		else 
		{
			break;
		}
		year++;
	}
	
	/* Get year in xx format */
	data->year = (uint8_t) (year - 2000U);
	
	/* Get month */
	for (data->month = 0; data->month < 12U; data->month++) 
	{
		if (RTC_LEAP_YEAR(year)) 
		{
			if (unix >= (uint32_t)RTC_Months[1][data->month]) 
			{
				unix -= RTC_Months[1][data->month];
			}
			else 
			{
				break;
			}
		} 
		else if (unix >= (uint32_t)RTC_Months[0][data->month]) 
		{
			unix -= RTC_Months[0][data->month];
		} 
		else
		{
			break;
		}
	}
	
	/* Get month */
	/* Month starts with 1 */
	data->month++;
	/* Get date */
	/* Date starts with 1 */
	data->date = unix + 1U;
}


void HAL_TIM_PeriodElapsedCallback(TIM_HandleTypeDef *htim)
{
	__HAL_TIM_CLEAR_FLAG(&htim3, TIM_FLAG_UPDATE);
   
	++triac_timer;
	if(triac_on_time == 0U) HAL_GPIO_WritePin(GPIOC, GPIO_PIN_8, GPIO_PIN_RESET);
	else if(triac_timer < triac_on_time) HAL_GPIO_WritePin(GPIOC, GPIO_PIN_8, GPIO_PIN_RESET);
    else if(triac_timer > (triac_on_time + TRIAC_ON_PULSE)) HAL_GPIO_WritePin(GPIOC, GPIO_PIN_8, GPIO_PIN_RESET);
	else HAL_GPIO_WritePin(GPIOC, GPIO_PIN_8, GPIO_PIN_SET);  
}


void Error_Handler(uint8_t function, uint8_t driver)
{
//    LogEvent.log_event = DRIVER_OR_FUNCTION_FAIL;
//    LogEvent.log_group = function;
//    LogEvent.log_type = driver;
//    LOGGER_Write();	
    RESTART_Init();
}


void FAN_SetControlType(uint8_t fan_ctrl_type)
{
    TIM_OC_InitTypeDef sConfigOC;
	GPIO_InitTypeDef GPIO_InitStruct;
    
    __HAL_RCC_TIM3_CLK_DISABLE();
    HAL_NVIC_DisableIRQ(EXTI15_10_IRQn);
    HAL_NVIC_DisableIRQ(TIM3_IRQn);
    HAL_TIM_Base_DeInit(&htim3);
    HAL_GPIO_DeInit(GPIOC, GPIO_PIN_8);
    
    if (fan_ctrl_type == 0U)        // simple On / Off thermostat control 
    {
    }
    else if (fan_ctrl_type == 1U)   // 3 speed fan motor connected to 3 triac controled output interface pcb
    {
    }
    else if (fan_ctrl_type == 2U)   // leading edge triac fan speed control with interface pcb 
    {
        GPIO_InitStruct.Pin = GPIO_PIN_8;
        GPIO_InitStruct.Mode = GPIO_MODE_OUTPUT_PP;
        GPIO_InitStruct.Pull = GPIO_NOPULL;
        GPIO_InitStruct.Speed = GPIO_SPEED_FREQ_LOW;
        HAL_GPIO_Init(GPIOC, &GPIO_InitStruct);
        
        MX_TIM3_Init();
    }
    else if (fan_ctrl_type == 3U)   // BLDC fan motor speed control with interface pcb DE-151218
    {       
        __HAL_RCC_TIM3_CLK_ENABLE();
        __HAL_RCC_GPIOC_CLK_ENABLE();
        
        htim3.Instance = TIM3;
        htim3.Init.Prescaler = 9999U;
        htim3.Init.CounterMode = TIM_COUNTERMODE_UP;
        htim3.Init.Period = 100U;
        htim3.Init.ClockDivision = TIM_CLOCKDIVISION_DIV1;
        htim3.Init.AutoReloadPreload = TIM_AUTORELOAD_PRELOAD_DISABLE;
	
        if (HAL_TIM_PWM_Init(&htim3) != HAL_OK)
        {
            Error_Handler(MAIN_FUNC, TMR_DRIVER);
        }

        sConfigOC.OCMode = TIM_OCMODE_PWM1;
        sConfigOC.Pulse = fan_speed;
        sConfigOC.OCPolarity = TIM_OCPOLARITY_HIGH;
        sConfigOC.OCFastMode = TIM_OCFAST_DISABLE;
        
        if (HAL_TIM_PWM_ConfigChannel(&htim3, &sConfigOC, TIM_CHANNEL_3) != HAL_OK)
        {
            Error_Handler(MAIN_FUNC, TMR_DRIVER);
        }

        /**TIM3 GPIO Configuration    
        PC8     ------> TIM3_CH3 
        */
        GPIO_InitStruct.Pin = GPIO_PIN_8;
        GPIO_InitStruct.Mode = GPIO_MODE_AF_PP;
        GPIO_InitStruct.Pull = GPIO_NOPULL;
        GPIO_InitStruct.Speed = GPIO_SPEED_FREQ_LOW;
        GPIO_InitStruct.Alternate = GPIO_AF2_TIM3;
        HAL_GPIO_Init(GPIOC, &GPIO_InitStruct);
        
        HAL_TIM_PWM_Start(&htim3, TIM_CHANNEL_3);
    }
}


void FAN_SetSpeed(uint8_t fan_speed)
{
    HAL_TIM_Base_Stop_IT(&htim3);
    HAL_NVIC_DisableIRQ(TIM3_IRQn);
	HAL_NVIC_DisableIRQ(EXTI15_10_IRQn);
    __HAL_GPIO_EXTI_CLEAR_IT(GPIO_PIN_13);
	__HAL_TIM_CLEAR_FLAG(&htim3, TIM_FLAG_UPDATE);
    HAL_GPIO_WritePin(GPIOC, GPIO_PIN_8, GPIO_PIN_RESET);
    
    fan_rpm_pulse = 0U;
	triac_on_time = 0U;
	triac_timer = 0U;
    
	if(fan_speed != FAN_OFF)
	{
		triac_on_time = fan_speed;
		HAL_NVIC_EnableIRQ(EXTI15_10_IRQn);
	}
}


void HAL_GPIO_EXTI_Callback(uint16_t GPIO_Pin)
{
	if(GPIO_Pin == GPIO_PIN_13)
	{
        HAL_TIM_Base_Stop_IT(&htim3);
        HAL_NVIC_DisableIRQ(TIM3_IRQn);
		__HAL_GPIO_EXTI_CLEAR_IT(GPIO_PIN_13);
        HAL_GPIO_WritePin(GPIOC, GPIO_PIN_8, GPIO_PIN_RESET);
        triac_timer = 0U;
        __HAL_TIM_SET_COUNTER(&htim3, 0U);
        
        if(!IsFANCOIL_RPM_SensorErrorActiv())
        {
            HAL_NVIC_EnableIRQ(TIM3_IRQn);
            HAL_TIM_Base_Start_IT(&htim3);            
        }
        else
        {
            HAL_NVIC_DisableIRQ(EXTI15_10_IRQn);
        }
	}
	else if(GPIO_Pin == GPIO_PIN_14)
	{
		__HAL_GPIO_EXTI_CLEAR_IT(GPIO_PIN_14);
		++fan_rpm_pulse;
	}
}


#ifndef	USE_DEBUGGER
void MX_IWDG_Init(void)
{
    hiwdg.Instance = IWDG;
    hiwdg.Init.Prescaler = IWDG_PRESCALER_32;
    hiwdg.Init.Reload = 4095;
    HAL_IWDG_Init(&hiwdg);
}
#endif


static void RAM_Init(void)
{
    uint16_t bt = 16U;
    uint8_t ee_buff[16];
    
    BSP_EEPROM_ReadBuffer(ee_buff, EE_THERMOSTAT_MAX_COOLING_TEMP, &bt);
    thermostat_max_cooling_temperature = ((ee_buff[0] << 8U) + ee_buff[1]);
    thermostat_min_heating_temperature = ((ee_buff[2] << 8U) + ee_buff[3]);
    thermostat_error_duraton = (ee_buff[4] << 8U) + ee_buff[5];
    thermostat_ambient_ntc_offset = (ee_buff[6] << 8U) + ee_buff[7];
    thermostat_fancoil_ntc_offset = (ee_buff[8] << 8U) + ee_buff[9];
    fancoil_temperature_limit_mode = ee_buff[10];
    thermostat_flags_memo = (ee_buff[11] << 24U) + (ee_buff[12] << 16U) + (ee_buff[13] << 8U) + ee_buff[14];
    
    BSP_EEPROM_ReadBuffer(ee_buff, EE_THERMOSTAT_OPERATION_MODE, &bt);
    thermostat_operation_mode = ee_buff[0];
    thermostat_max_setpoint_temperature  = ee_buff[1];
    thermostat_min_setpoint_temperature  = ee_buff[2];
    fan_speed_treshold  = ee_buff[3];
    fan_low_speed_band  = ee_buff[4];
    fan_middle_speed_band  = ee_buff[5];
    onewire_interface_address  = ee_buff[6];
    rs485_interface_address = (ee_buff[7] << 8U) + ee_buff[8];
    fan_control_type  = ee_buff[9];
    freezing_protection_temperature = ee_buff[10];
    fan_night_quiet_mode_start_hour = ee_buff[11];
    temperature_setpoint = ee_buff[12];
    
    if((thermostat_max_cooling_temperature > 500U) || (thermostat_max_cooling_temperature < 100U)) thermostat_max_cooling_temperature = 500U;
    if((thermostat_min_heating_temperature > 500U) || (thermostat_min_heating_temperature < 100U)) thermostat_min_heating_temperature = 100U;
    if((thermostat_error_duraton > 240U) || (thermostat_error_duraton < 1U)) thermostat_error_duraton = 1U;
    if((thermostat_ambient_ntc_offset > 100) || (thermostat_ambient_ntc_offset < -100) )thermostat_ambient_ntc_offset = 0;
    if((thermostat_fancoil_ntc_offset > 100) || (thermostat_fancoil_ntc_offset < -100) )thermostat_fancoil_ntc_offset = 0;
    if(fancoil_temperature_limit_mode > 1U) fancoil_temperature_limit_mode = 0U;
    if(thermostat_operation_mode > 3U) thermostat_operation_mode = 3U;
    if((thermostat_max_setpoint_temperature > 40U) || (thermostat_max_setpoint_temperature < 10U)) thermostat_max_setpoint_temperature = 40U;
    if((thermostat_min_setpoint_temperature > 40U) || (thermostat_min_setpoint_temperature < 10U)) thermostat_min_setpoint_temperature = 15U;
    if(fan_speed_treshold > 100U) fan_speed_treshold = 100U;
    if(fan_low_speed_band > 100U) fan_low_speed_band = 100U;
    if(fan_middle_speed_band > 100U) fan_middle_speed_band = 100U;
    if((onewire_interface_address > 9U) || (onewire_interface_address < 1U)) onewire_interface_address = 1U;
    if((rs485_interface_address > 65000U) || (rs485_interface_address < 100U)) rs485_interface_address = 100U;
    if(fan_control_type > 2U) fan_control_type = 0U;
    if((freezing_protection_temperature > 80U) || (freezing_protection_temperature < 5U)) freezing_protection_temperature = 80U;
    if(fan_night_quiet_mode_start_hour > 23U) fan_night_quiet_mode_start_hour = 7U;
    if((temperature_setpoint & 0x3FU) > thermostat_max_setpoint_temperature) temperature_setpoint = (temperature_setpoint & 0xC0U) + thermostat_max_setpoint_temperature;
    if((temperature_setpoint & 0x3FU) < thermostat_min_setpoint_temperature) temperature_setpoint = (temperature_setpoint & 0xC0U) + thermostat_min_setpoint_temperature;
}

static void MPU_Config(void)
{
	MPU_Region_InitTypeDef MPU_InitStruct;

	/* Disable the MPU */
	HAL_MPU_Disable();

	/* Configure the MPU attributes as WT for SRAM */
	MPU_InitStruct.Enable           = MPU_REGION_ENABLE;
	MPU_InitStruct.BaseAddress      = 0x20010000U;
	MPU_InitStruct.Size             = MPU_REGION_SIZE_256KB;
	MPU_InitStruct.AccessPermission = MPU_REGION_FULL_ACCESS;
	MPU_InitStruct.IsBufferable     = MPU_ACCESS_NOT_BUFFERABLE;
	MPU_InitStruct.IsCacheable      = MPU_ACCESS_CACHEABLE;
	MPU_InitStruct.IsShareable      = MPU_ACCESS_SHAREABLE;
	MPU_InitStruct.Number           = MPU_REGION_NUMBER0;
	MPU_InitStruct.TypeExtField     = MPU_TEX_LEVEL0;
	MPU_InitStruct.SubRegionDisable = 0U;
	MPU_InitStruct.DisableExec      = MPU_INSTRUCTION_ACCESS_ENABLE;
	HAL_MPU_ConfigRegion(&MPU_InitStruct);

	/* Configure the MPU attributes for Quad-SPI area to strongly ordered
	 This setting is essentially needed to avoid MCU blockings! 
	 See also STM Application Note AN4861 */
	MPU_InitStruct.Enable           = MPU_REGION_ENABLE;
	MPU_InitStruct.Number           = MPU_REGION_NUMBER2;
	MPU_InitStruct.BaseAddress      = 0x90000000U;
	MPU_InitStruct.Size             = MPU_REGION_SIZE_256MB;
	MPU_InitStruct.SubRegionDisable = 0U;
	MPU_InitStruct.TypeExtField     = MPU_TEX_LEVEL0;
	MPU_InitStruct.AccessPermission = MPU_REGION_NO_ACCESS;
	MPU_InitStruct.DisableExec      = MPU_INSTRUCTION_ACCESS_DISABLE;
	MPU_InitStruct.IsShareable      = MPU_ACCESS_SHAREABLE;
	MPU_InitStruct.IsCacheable      = MPU_ACCESS_NOT_CACHEABLE;
	MPU_InitStruct.IsBufferable     = MPU_ACCESS_NOT_BUFFERABLE;
	HAL_MPU_ConfigRegion(&MPU_InitStruct);

	/* Configure the MPU attributes for the QSPI 64MB to normal memory Cacheable, must reflect the real memory size */
	MPU_InitStruct.Enable           = MPU_REGION_ENABLE;
	MPU_InitStruct.Number           = MPU_REGION_NUMBER3;
	MPU_InitStruct.BaseAddress      = 0x90000000U;
	MPU_InitStruct.Size             = MPU_REGION_SIZE_16MB; // Set region size according to the QSPI memory size
	MPU_InitStruct.SubRegionDisable = 0U;
	MPU_InitStruct.TypeExtField     = MPU_TEX_LEVEL0;
	MPU_InitStruct.AccessPermission = MPU_REGION_FULL_ACCESS;
	MPU_InitStruct.DisableExec      = MPU_INSTRUCTION_ACCESS_DISABLE;
	MPU_InitStruct.IsShareable      = MPU_ACCESS_SHAREABLE;
	MPU_InitStruct.IsCacheable      = MPU_ACCESS_CACHEABLE;
	MPU_InitStruct.IsBufferable     = MPU_ACCESS_NOT_BUFFERABLE;
	HAL_MPU_ConfigRegion(&MPU_InitStruct);

	/* Configure the MPU attributes for SDRAM_Banks area to strongly ordered
	 This setting is essentially needed to avoid MCU blockings!
	 See also STM Application Note AN4861 */
	MPU_InitStruct.Enable           = MPU_REGION_ENABLE;
	MPU_InitStruct.Number           = MPU_REGION_NUMBER4;
	MPU_InitStruct.BaseAddress      = 0xC0000000U;
	MPU_InitStruct.Size             = MPU_REGION_SIZE_512MB;
	MPU_InitStruct.SubRegionDisable = 0U;
	MPU_InitStruct.TypeExtField     = MPU_TEX_LEVEL0;
	MPU_InitStruct.AccessPermission = MPU_REGION_NO_ACCESS;
	MPU_InitStruct.DisableExec      = MPU_INSTRUCTION_ACCESS_DISABLE;
	MPU_InitStruct.IsShareable      = MPU_ACCESS_SHAREABLE;
	MPU_InitStruct.IsCacheable      = MPU_ACCESS_NOT_CACHEABLE;
	MPU_InitStruct.IsBufferable     = MPU_ACCESS_NOT_BUFFERABLE;
	HAL_MPU_ConfigRegion(&MPU_InitStruct);

	/* Configure the MPU attributes for SDRAM 16MB to normal memory Cacheable */
	MPU_InitStruct.Enable           = MPU_REGION_ENABLE;
	MPU_InitStruct.Number           = MPU_REGION_NUMBER5;
	MPU_InitStruct.BaseAddress      = 0xC0000000U;
	MPU_InitStruct.Size             = MPU_REGION_SIZE_8MB;
	MPU_InitStruct.SubRegionDisable = 0U;
	MPU_InitStruct.TypeExtField     = MPU_TEX_LEVEL0;
	MPU_InitStruct.AccessPermission = MPU_REGION_FULL_ACCESS;
	MPU_InitStruct.DisableExec      = MPU_INSTRUCTION_ACCESS_ENABLE;
	MPU_InitStruct.IsShareable      = MPU_ACCESS_SHAREABLE;
	MPU_InitStruct.IsCacheable      = MPU_ACCESS_CACHEABLE;
	MPU_InitStruct.IsBufferable     = MPU_ACCESS_NOT_BUFFERABLE;
	HAL_MPU_ConfigRegion(&MPU_InitStruct);

	/* Enable the MPU */
	HAL_MPU_Enable(MPU_PRIVILEGED_DEFAULT);
	
	/* Disable FMC bank1 (0x6000 0000 - 0x6FFF FFFF), since it is not used.
	This setting avoids unnedded speculative access to the first FMC bank.
	See also STM Application Note AN4861 */
	FMC_Bank1->BTCR[0] = 0x000030D2U;
}

static void CACHE_Config(void)
{
	SCB_EnableICache();
	SCB_EnableDCache();	
}
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

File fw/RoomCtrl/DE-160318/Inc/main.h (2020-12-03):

/**
  ******************************************************************************
  * File Name          : mXconstants.h
  * Description        : This file contains the common defines of the application
  ******************************************************************************
  *
  * COPYRIGHT(c) 2016 STMicroelectronics
  *
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
  ******************************************************************************
  */
  
/* Base address of the Flash sectors */
#define ADDR_FLASH_PAGE_0     ((uint32_t)0x08000000) /* Base @ of Page 0, 1 Kbytes */
#define ADDR_FLASH_PAGE_1     ((uint32_t)0x08000400) /* Base @ of Page 1, 1 Kbytes */
#define ADDR_FLASH_PAGE_2     ((uint32_t)0x08000800) /* Base @ of Page 2, 1 Kbytes */
#define ADDR_FLASH_PAGE_3     ((uint32_t)0x08000C00) /* Base @ of Page 3, 1 Kbytes */
#define ADDR_FLASH_PAGE_4     ((uint32_t)0x08001000) /* Base @ of Page 4, 1 Kbytes */
#define ADDR_FLASH_PAGE_5     ((uint32_t)0x08001400) /* Base @ of Page 5, 1 Kbytes */
#define ADDR_FLASH_PAGE_6     ((uint32_t)0x08001800) /* Base @ of Page 6, 1 Kbytes */
#define ADDR_FLASH_PAGE_7     ((uint32_t)0x08001C00) /* Base @ of Page 7, 1 Kbytes */
#define ADDR_FLASH_PAGE_8     ((uint32_t)0x08002000) /* Base @ of Page 8, 1 Kbytes */
#define ADDR_FLASH_PAGE_9     ((uint32_t)0x08002400) /* Base @ of Page 9, 1 Kbytes */
#define ADDR_FLASH_PAGE_10    ((uint32_t)0x08002800) /* Base @ of Page 10, 1 Kbytes */
#define ADDR_FLASH_PAGE_11    ((uint32_t)0x08002C00) /* Base @ of Page 11, 1 Kbytes */
#define ADDR_FLASH_PAGE_12    ((uint32_t)0x08003000) /* Base @ of Page 12, 1 Kbytes */
#define ADDR_FLASH_PAGE_13    ((uint32_t)0x08003400) /* Base @ of Page 13, 1 Kbytes */
#define ADDR_FLASH_PAGE_14    ((uint32_t)0x08003800) /* Base @ of Page 14, 1 Kbytes */
#define ADDR_FLASH_PAGE_15    ((uint32_t)0x08003C00) /* Base @ of Page 15, 1 Kbytes */
#define ADDR_FLASH_PAGE_16    ((uint32_t)0x08004000) /* Base @ of Page 16, 1 Kbytes */
#define ADDR_FLASH_PAGE_17    ((uint32_t)0x08004400) /* Base @ of Page 17, 1 Kbytes */
#define ADDR_FLASH_PAGE_18    ((uint32_t)0x08004800) /* Base @ of Page 18, 1 Kbytes */
#define ADDR_FLASH_PAGE_19    ((uint32_t)0x08004C00) /* Base @ of Page 19, 1 Kbytes */
#define ADDR_FLASH_PAGE_20    ((uint32_t)0x08005000) /* Base @ of Page 20, 1 Kbytes */
#define ADDR_FLASH_PAGE_21    ((uint32_t)0x08005400) /* Base @ of Page 21, 1 Kbytes */
#define ADDR_FLASH_PAGE_22    ((uint32_t)0x08005800) /* Base @ of Page 22, 1 Kbytes */
#define ADDR_FLASH_PAGE_23    ((uint32_t)0x08005C00) /* Base @ of Page 23, 1 Kbytes */
#define ADDR_FLASH_PAGE_24    ((uint32_t)0x08006000) /* Base @ of Page 24, 1 Kbytes */
#define ADDR_FLASH_PAGE_25    ((uint32_t)0x08006400) /* Base @ of Page 25, 1 Kbytes */
#define ADDR_FLASH_PAGE_26    ((uint32_t)0x08006800) /* Base @ of Page 26, 1 Kbytes */
#define ADDR_FLASH_PAGE_27    ((uint32_t)0x08006C00) /* Base @ of Page 27, 1 Kbytes */
#define ADDR_FLASH_PAGE_28    ((uint32_t)0x08007000) /* Base @ of Page 28, 1 Kbytes */
#define ADDR_FLASH_PAGE_29    ((uint32_t)0x08007400) /* Base @ of Page 29, 1 Kbytes */
#define ADDR_FLASH_PAGE_30    ((uint32_t)0x08007800) /* Base @ of Page 30, 1 Kbytes */
#define ADDR_FLASH_PAGE_31    ((uint32_t)0x08007C00) /* Base @ of Page 31, 1 Kbytes */
#define ADDR_FLASH_PAGE_32    ((uint32_t)0x08008000) /* Base @ of Page 32, 1 Kbytes */
#define ADDR_FLASH_PAGE_33    ((uint32_t)0x08008400) /* Base @ of Page 33, 1 Kbytes */
#define ADDR_FLASH_PAGE_34    ((uint32_t)0x08008800) /* Base @ of Page 34, 1 Kbytes */
#define ADDR_FLASH_PAGE_35    ((uint32_t)0x08008C00) /* Base @ of Page 35, 1 Kbytes */
#define ADDR_FLASH_PAGE_36    ((uint32_t)0x08009000) /* Base @ of Page 36, 1 Kbytes */
#define ADDR_FLASH_PAGE_37    ((uint32_t)0x08009400) /* Base @ of Page 37, 1 Kbytes */
#define ADDR_FLASH_PAGE_38    ((uint32_t)0x08009800) /* Base @ of Page 38, 1 Kbytes */
#define ADDR_FLASH_PAGE_39    ((uint32_t)0x08009C00) /* Base @ of Page 39, 1 Kbytes */
#define ADDR_FLASH_PAGE_40    ((uint32_t)0x0800A000) /* Base @ of Page 40, 1 Kbytes */
#define ADDR_FLASH_PAGE_41    ((uint32_t)0x0800A400) /* Base @ of Page 41, 1 Kbytes */
#define ADDR_FLASH_PAGE_42    ((uint32_t)0x0800A800) /* Base @ of Page 42, 1 Kbytes */
#define ADDR_FLASH_PAGE_43    ((uint32_t)0x0800AC00) /* Base @ of Page 43, 1 Kbytes */
#define ADDR_FLASH_PAGE_44    ((uint32_t)0x0800B000) /* Base @ of Page 44, 1 Kbytes */
#define ADDR_FLASH_PAGE_45    ((uint32_t)0x0800B400) /* Base @ of Page 45, 1 Kbytes */
#define ADDR_FLASH_PAGE_46    ((uint32_t)0x0800B800) /* Base @ of Page 46, 1 Kbytes */
#define ADDR_FLASH_PAGE_47    ((uint32_t)0x0800BC00) /* Base @ of Page 47, 1 Kbytes */
#define ADDR_FLASH_PAGE_48    ((uint32_t)0x0800C000) /* Base @ of Page 48, 1 Kbytes */
#define ADDR_FLASH_PAGE_49    ((uint32_t)0x0800C400) /* Base @ of Page 49, 1 Kbytes */
#define ADDR_FLASH_PAGE_50    ((uint32_t)0x0800C800) /* Base @ of Page 50, 1 Kbytes */
#define ADDR_FLASH_PAGE_51    ((uint32_t)0x0800CC00) /* Base @ of Page 51, 1 Kbytes */
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

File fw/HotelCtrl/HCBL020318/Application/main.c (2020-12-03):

/**
  * @file    main.c 
  * @author  eldar6776@hotmail.com
  * @version V1,0
  * @date    06.03.2017
  * @brief   Main Program
  */
  
#include "ff.h"	
#include "main.h"
#include "buzzer.h"
#include "command.h"
#include "flash_if.h"
#include "i2c_eeprom.h"
#include "stm32f429i_lcd.h"
#include "stm32f4xx_fmc.h"

/* Constante ----------------------------------------------------------------*/
const char sys_info[] = "HW: RED_DRAGON_F429, REV:1,0;      FW: HCBL020318 ";

/* Private typedef -----------------------------------------------------------*/
#define TASTER_S2_PORT				GPIOA
#define TASTER_S2_PIN				GPIO_Pin_0
#define TASTER_S2_CLK				RCC_AHB1Periph_GPIOA


#define LED_GPIO_PORT           	GPIOD
#define LED1_GPIO_PIN          		GPIO_Pin_11
#define LED2_GPIO_PIN          		GPIO_Pin_12
#define LED_GPIO_CLK           		RCC_AHB1Periph_GPIOD

/* Private define ------------------------------------------------------------*/
/* Private macro -------------------------------------------------------------*/
/* Private variables ---------------------------------------------------------*/
extern FATFS fatfs;
extern FIL file;
extern FIL fileR;
extern DIR dir;
extern FILINFO fno;

/* Private function prototypes -----------------------------------------------*/

uint32_t system_id;
uint32_t system_config;

pFunction Jump_To_Application;
uint32_t JumpAddress;

__IO uint32_t TimingDelay;


/*****************************************************************************
**   Main Function  main()
******************************************************************************/
int main(void)
{
    GPIO_InitTypeDef  GPIO_InitStructure;

    SysTick_Config(SystemCoreClock / 1000);
	RCC_AHB1PeriphClockCmd(RCC_AHB1Periph_CRC, ENABLE);
    RCC_ClearFlag();
    
	RCC_AHB1PeriphClockCmd(TASTER_S2_CLK, ENABLE);
	RCC_APB2PeriphClockCmd(RCC_APB2Periph_SYSCFG, ENABLE);
	GPIO_InitStructure.GPIO_Mode = GPIO_Mode_IN;
	GPIO_InitStructure.GPIO_PuPd = GPIO_PuPd_NOPULL;
	GPIO_InitStructure.GPIO_Pin = TASTER_S2_PIN;
	GPIO_Init(TASTER_S2_PORT, &GPIO_InitStructure);
    
	RCC_AHB1PeriphClockCmd(RCC_AHB1Periph_GPIOD , ENABLE);
	GPIO_InitStructure.GPIO_Mode = GPIO_Mode_OUT;
	GPIO_InitStructure.GPIO_OType = GPIO_OType_PP;
	GPIO_InitStructure.GPIO_PuPd = GPIO_PuPd_UP;
	GPIO_InitStructure.GPIO_Speed = GPIO_Speed_50MHz;

	GPIO_InitStructure.GPIO_Pin = GPIO_Pin_3;
	GPIO_Init(GPIOD, &GPIO_InitStructure);
	GPIO_ResetBits(GPIOD, GPIO_Pin_3);
    
	I2C_EERPOM_Init();
    
	system_config = (uint8_t)I2C_EERPOM_ReadByte16(I2C_EE_READ_PAGE_0, EE_SYSTEM_CONFIG_ADDRESS);
	
	if(!IsBootloaderRequested() && (GPIO_ReadInputDataBit(TASTER_S2_PORT, TASTER_S2_PIN) == Bit_RESET))
	{
		ApplicationExe();
	}
		
	LCD_Init(); 
	LCD_LayerInit();
	LTDC_Cmd(ENABLE);
	LCD_SetLayer(LCD_FOREGROUND_LAYER);
	LCD_Clear(LIGHTBLUE);
	LCD_SetTextColor(WHITE);
	LCD_SetBackColor(LIGHTBLUE);
	LCD_DisplayStringLine(LCD_LINE_2, (uint8_t*)"    BOOTLOADER AKTIVAN");
	GPIO_WriteBit(GPIOD, GPIO_Pin_3, Bit_SET);
	TimingDelay = 100;
	while(TimingDelay) continue;
	GPIO_WriteBit(GPIOD, GPIO_Pin_3, Bit_RESET);
	/* Initialises the File System*/
	if (f_mount(&fatfs, "0:", 0) != FR_OK ) 
	{
		BootloaderSDcardError();
		I2C_EERPOM_WriteByte16(I2C_EE_WRITE_PAGE_0, EE_SYSTEM_CONFIG_ADDRESS, (uint8_t) system_config);
		LCD_DisplayStringLine(LCD_LINE_4, (uint8_t*)"Greska kod citanja kartice");
		LCD_DisplayStringLine(LCD_LINE_5, (uint8_t*)"1. SD kartica nije ubacena");
		LCD_DisplayStringLine(LCD_LINE_6, (uint8_t*)"2. SD kartica neispravna");
		LCD_DisplayStringLine(LCD_LINE_7, (uint8_t*)"3. pogresan format SD kartice");
		LCD_DisplayStringLine(LCD_LINE_10, (uint8_t*)"Restart aplikacije za 2 sekunde");
		TimingDelay = 2000;
		while(TimingDelay) continue;
		ApplicationExe();
	}
	/* Flash unlock */
	FLASH_If_FlashUnlock();
	COMMAND_Download();
	GPIO_WriteBit(GPIOD, GPIO_Pin_3, Bit_SET);
	TimingDelay = 100;
	while(TimingDelay) continue;
	GPIO_WriteBit(GPIOD, GPIO_Pin_3, Bit_RESET);
	TimingDelay = 100;
	while(TimingDelay) continue;
	GPIO_WriteBit(GPIOD, GPIO_Pin_3, Bit_SET);
	TimingDelay = 100;
	while(TimingDelay) continue;
	GPIO_WriteBit(GPIOD, GPIO_Pin_3, Bit_RESET);
	BootloaderUpdateSucces();
	I2C_EERPOM_WriteByte16(I2C_EE_WRITE_PAGE_0, EE_SYSTEM_CONFIG_ADDRESS, (uint8_t) system_config);
	LCD_DisplayStringLine(LCD_LINE_8, (uint8_t*)"-upis firmware-a uspjesan");
	LCD_DisplayStringLine(LCD_LINE_10, (uint8_t*)"Start aplikacije za 3 sekunde");
	TimingDelay = 3000;
	while(TimingDelay) continue;
	NVIC_SystemReset();
	
	while (1) 
	{
		LED_GPIO_PORT->ODR ^= LED2_GPIO_PIN;
		Delay(500);
	}
}

void ApplicationExe(void)
{
    if (((*(__IO uint32_t*)APPLICATION_ADDRESS) & 0x2FFE0000 ) == 0x20000000)
    {
        I2C_DeInit(I2C2);
        LTDC_DeInit();
        FMC_SDRAMDeInit(FMC_Bank2_SDRAM);
        RCC_AHB1PeriphClockCmd(RCC_AHB1Periph_CRC, DISABLE);
        GPIO_DeInit(GPIOA);
        GPIO_DeInit(GPIOB);
        GPIO_DeInit(GPIOC);
        GPIO_DeInit(GPIOD);
        GPIO_DeInit(GPIOE);
        GPIO_DeInit(GPIOF);
        GPIO_DeInit(GPIOG);
        GPIO_DeInit(GPIOH);
        RCC_DeInit();
        RCC_ClearFlag();
		/* Jump to user application */
		JumpAddress = *(__IO uint32_t*) (APPLICATION_ADDRESS + 4);
		Jump_To_Application = (pFunction) JumpAddress;
		/* Initialize user application's Stack Pointer */
		__set_MSP(*(__IO uint32_t*) APPLICATION_ADDRESS);
		Jump_To_Application();
    }
	GPIO_WriteBit(GPIOD, GPIO_Pin_3, Bit_SET);
	TimingDelay = 2000;
	while(TimingDelay) continue;
	GPIO_WriteBit(GPIOD, GPIO_Pin_3, Bit_RESET);
	LCD_Clear(LIGHTBLUE);
	LCD_DisplayStringLine(LCD_LINE_2, (uint8_t*)"   GRESKA FIRMWARE-a");
	LCD_DisplayStringLine(LCD_LINE_6, (uint8_t*)"1. iskljuci napajanje");
	LCD_DisplayStringLine(LCD_LINE_7, (uint8_t*)"2. na micro SD karticu");
	LCD_DisplayStringLine(LCD_LINE_8, (uint8_t*)"	upisi ispravan fajl");
	LCD_DisplayStringLine(LCD_LINE_9, (uint8_t*)"3. ukljuci napajanje");
	Fail_Handler();
}

void Fail_Handler(void)
{
	while(1)
	{
		/* Toggle Red LED */
		LED_GPIO_PORT->ODR ^= LED1_GPIO_PIN;
		Delay(50);
	}
}
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

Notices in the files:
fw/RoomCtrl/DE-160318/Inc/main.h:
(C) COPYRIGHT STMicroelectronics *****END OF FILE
